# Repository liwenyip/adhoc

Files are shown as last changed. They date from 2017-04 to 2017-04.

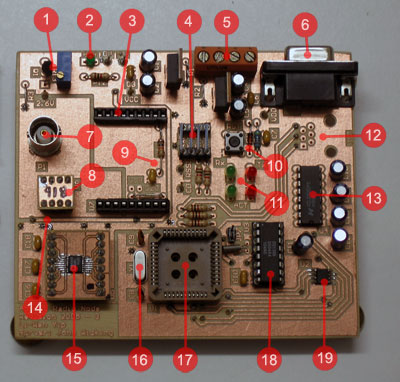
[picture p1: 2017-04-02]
docs/images/hardware/2005pcb3.jpg

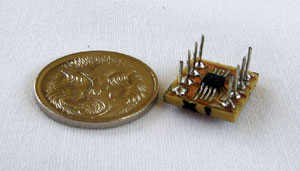
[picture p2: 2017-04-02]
docs/images/hardware/adg918-small.jpg

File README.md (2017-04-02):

# Remote Ad Hoc Sensor Networks
by Li-Wen Yip, 2005

This is my undergraduate honours thesis, completed in 2005 as part of my BE(Computer Systems).

**tl;dr**: It involved building some circuit boards with antennae, and writing a lot of code to make the circuit boards talk to each other wirelessly.

## Quick Links

- **[Website](https://liwenyip.github.io/adhoc)**: Provides a good overview of the project, and if nothing else is a great example of cutting edge web design in 2006.
- **[Presentations](Presentations)**: Also provides a good overview of the project. The first one has speaker notes in the `ppt` file; the other two don't have any speaker notes for some reason so they may make limited sense.
- **[Final report](YipThesis2005.pdf)** (PDF, 188 pages): Contains all of the juicy technical details.
- **[PCB designs](Appendix%20X%20-%20%20PCB%20Designs), [Microcontroller code](Appendix%20E%20-%20Microcontroller%20Code), [ns-2 simulator code](Appendix%20D%20-%20ns-2%20Simulation)**: Just in case you want to replicate my work.

## Licence

All of my work is published under the [MIT Licence](LICENCE.md).

## Previous and subsequent work

My thesis was a continuation of previous work by [Nigel Sim](https://eresearch.jcu.edu.au/contact/past-members/nigel-sim) (2003) and [Steven Sloots](https://au.linkedin.com/in/steven-sloots-38b22927) (2004). If you want to know more about their work, I can put you in touch with them. (I do have copies of their thesis reports, but they aren't mine to publish.)

The project was continued in 2006 by [William Harrington](http://www.harringtonsystems.com.au).

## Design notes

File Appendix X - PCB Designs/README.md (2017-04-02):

# PCB Designs

I believe these were all done using [Protel](http://www.altium.com).

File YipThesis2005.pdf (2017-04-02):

## School Of Engineering

## REMOTE AD HOC SENSOR NETWORKS

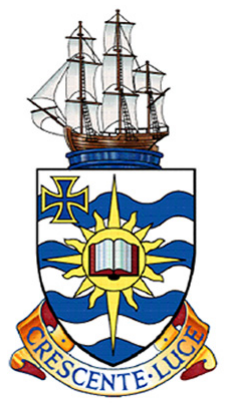
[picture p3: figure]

## Li-Wen Yip

### Bachelor of Engineering

in

### Computer Systems Engineering

# Thesis

October 2004

JAMES COOK UNIVERSITY

# SCHOOL OF ENGINEERING

EG4010

## Computer Systems Engineering

## REMOTE AD HOC SENSOR NETWORKS

Li-Wen Yip

Thesis submitted to the School of Engineering in partial fulfilment of the requirements for the degree of

## Bachelor of Engineering with Honours

## (Computer Systems)

11 November 2005

Preface | Remote Ad Hoc Sensor Networks

ABSTRACT

Australia’s vast geographical expanses present challenging communications problems for data collection, which often require the use of high power radio links. Many of these scenarios lend themselves to the use of multi-hop ad hoc sensor networks, which can provide an alternative, more flexible and economical solution. However, little if any research has been conducted into developing network protocols suitable for these scenarios, which are characterised by remote and inaccessible locations, sparse topologies, and link ranges of up to 10 kilometres.

The first goal of this project was to develop a dynamic address allocation algorithm to realise the goal of zero configuration, with minimal energy overhead. The second goal was to develop an energy efficient media access control protocol, to maximise the battery life of each node.

The MAC protocol features a synchronised wakeup, which suits the periodic bulk data transfer typical of data logging applications. During inactive periods, a preamble sampling technique provides dramatic power savings whilst maintaining minimal network connectivity. The sampling frequency is dynamically optimised for maximum power savings, based on anticipated variations in local traffic levels.

The address allocation protocol is based on an existing technique, in which each node possesses a block of addresses. These addresses may be autonomously allocated to other nodes without distributed agreement, which results in a protocol with extremely low control overhead and minimal power consumption. This technique has been optimised to further reduce the control overhead for each operation, and avoid unnecessarily flooding the network with search requests.

A microcontroller based hardware platform was constructed, and was used to develop, implement and test the aforementioned protocols. The MAC protocol has been implemented and tested on the microcontroller, whilst the addressing protocol has been implemented in the ns-2 wireless network simulator. The design of the hardware platform has also been improved, improving energy efficiency and performance.

Li-Wen Yip | School of Engineering, James Cook University | i

Preface | Remote Ad Hoc Sensor Networks

ACKNOWLEDGEMENTS

I would like to express my sincere thanks to Mr John Wicking. Without his invaluable advice and direction, this thesis project would not have been possible. I would also like to thank the ECE technical staff, whose immeasurable knowledge, experience, and common sense have saved me from many headaches.

To my friends, for sharing in the insane antics which have helped me maintain my humanity and sense of humour throughout this year, and for reminding me that there is more to life than thesis.

Finally, to my family, for supporting and encouraging me through the greater part of my life.

Li-Wen Yip | School of Engineering, James Cook University | ii

Preface | Remote Ad Hoc Sensor Networks

STATEMENT OF ACCESS

I, the undersigned, the author of this Thesis, understand that James Cook University will make the Thesis available for use within the University Library, by microfilm, or other means, and to allow access to users in other approved libraries.

All users consulting this Thesis will have to sign the following statement:

“In consulting this Thesis, I agree not to copy or closely paraphrase it in whole or in part without the written consent of the author; and to make proper public written acknowledgement for any assistance, which I have obtained from it.”

Beyond this, I do not wish to place any restriction on access to this Thesis.

Li-Wen Yip | Date
Li-Wen Yip | School of Engineering, James Cook University | iii

Preface | Remote Ad Hoc Sensor Networks

SOURCE DECLARATION

I declare that this Thesis is my own work and has not been submitted in any for another Degree or Diploma at any university or other institution of tertiary education. Information derived from the published or unpublished work of others has been acknowledged in the text and a list of references given.

Li-Wen Yip | Date
Li-Wen Yip | School of Engineering, James Cook University | iv

Preface | Remote Ad Hoc Sensor Networks

TABLE OF CONTENTS

Li-Wen Yip | School of Engineering, James Cook University | v

Preface | Remote Ad Hoc Sensor Networks
Li-Wen Yip | School of Engineering, James Cook University | vi

Preface | Remote Ad Hoc Sensor Networks
4.4.3 | Design | 87
4.4.4 | Implementation | 89
CHAPTER 5 DISCUSSION OF RESULTS | 90
5.1.1 | Hardware Architecture | 90
5.1.2 | Manchester Encoding and Decoding | 90
5.1.3 | MAC Protocol | 91
5.1.4 | Address Allocation Protocol | 92
CHAPTER 6 CONCLUSION | 93
CHAPTER 7 CONTINUATIONS AND EXTENSIONS | 95

### 7.1 Software Simulation | 95

### 7.2 Location Discovery | 96

REFERENCES | 97
APPENDIX A SOFTWARE FLOW CHARTS | 101
A.1 | Encoding and Decoding | 101
A.2 | Address Allocation | 106
APPENDIX B SCHEMATIC DIAGRAMS | 115
APPENDIX C RAW DATA | 117
APPENDIX D NS-2 SIMULATION SOFTWARE | 118
APPENDIX E MICROCONTROLLER SOFTWARE LISTING | 126
E.1 | Header Files | 126
E.2 | Modules | 134
E.3 | Peripherals | 160
Li-Wen Yip | School of Engineering, James Cook University | vii

Preface | Remote Ad Hoc Sensor Networks

LIST OF FIGURES

Figure 3.18 - Carrier Detect (Active Low), No signal present, 5V/div, 1ms/div ........59

Figure 4.3 - Carrier board soldered directly to PCB; Coaxial cable soldered directly to

Li-Wen Yip | School of Engineering, James Cook University | viii

Preface | Remote Ad Hoc Sensor Networks
Figure 4.5 - Signal strength in OFF state (-110dBm) | 72
Figure 4.6 - Clock Detect Flag vs. Frequency | 77
Figure 4.7 - Message successfully received (The answer is 42!) | 79
Figure 4.8 - Power Consumption vs. Duty Cycle for X2010 Transceiver | 81
Figure A.1 – Frame Encoder | 101
Figure A.2 - Manchester Encoder | 102
Figure A.3 - Frame Decoder | 103
Figure A.4 - Manchester Decoder | 104
Figure A.5 - High Priority Interrupt Service Routine | 105
Figure A.6 - Node Startup Event | 106
Figure A.7 - Initialisation Timeout Event | 107
Figure A.8 - AREP Message Received Event | 108
Figure A.9 - NREP Message Received Event | 109
Figure A.10 - AREQ Message Received Event | 110
Figure A.11 - Allocation Timeout Event | 111
Figure A.12 - AACK Message Received Event | 112
Figure A.13 - ASRCH Message Received Event | 113
Figure A.14 - AREJ Message Received Event | 114
Figure B.1 - Node Rev 3 Schematic Diagram | 116
Li-Wen Yip | School of Engineering, James Cook University | ix

Preface | Remote Ad Hoc Sensor Networks

LIST OF TABLES

Table 3.1 - Classification of traffic rates | 53
Table 3.2 - Hardware Parameters | 53
Table 4.1 - Instruction Cycles for Encoding Operations | 75
Table 4.2 - Frequency and Duty cycle measurements | 75
Table 4.3 - Byte Waveforms | 76
Table 4.4 - Instruction Cycles for Decoding Operations | 78
Table 4.5 - Definition of Packet | 87
Table 4.6 - Definition of Node | 87
Table C.1 - X2010 Transceiver Power Consumption vs Duty Cycle | 117
Table D.1 - DAA.H | 118
Table D.1 - DAA.CC | 120
Table E.1 - MACROLIB.INC | 127
Table E.2 - PINCONNECTIONS.INC | 127
Table E.3 - SWSTACK.INC | 130
Table E.4 - BUFFERS.INC | 131
Table E.5 - MAIN.ASM | 134
Table E.6 - PHY.INC | 137
Table E.7 - PHY.ASM | 137
Table E.8 - MAC.INC | 145
Table E.9 - MAC.INC | 145
Table E.10 - SPI.ASM | 160
Table E.11 - RTC.INC | 162
Table E.12 - RTC.ASM | 162
Table E.13 - ROUTECACHE.ASM | 167
Table E.14 - SWTIMERS.ASM | 174
Li-Wen Yip | School of Engineering, James Cook University | x

Chapter 1: Introduction | Remote Ad Hoc Sensor Networks

Chapter 1

## INTRODUCTION

### 1.1 BACKGROUND

Ad hoc networking is currently a very active area of research at many institutions around the world. A subclass of ad hoc networks are ad hoc sensor networks, which are typically characterised by long battery life, low traffic rates, low power radios, and dense, well connected topologies. The sensor nodes integrate data collection, data processing and communications functions into a tiny package with long battery life.

There are several existing projects which are at an advanced level of development, including Berkley University Smart Dust, Crossbow Motes, and the TinyOS operating system. There have also been numerous publications presenting new protocols and techniques for media access control, power management, routing, and address allocation. However, little or no research has been specifically conducted into ad hoc sensor networks which feature sparse, minimally connected topologies, and a large geographical distance between nodes. The target application is an ad hoc radio network for environmental monitoring stations on the Great Barrier Reef, which will allow data to be collected and relayed back to the Australian Institute of Marine Sciences at Cape Cleveland. This data is currently collected by high power / long range radio links, which requires expensive and bulky batteries and radios, as well as a costly radio license.

The sparse topology, remote location, and typically harsh environmental conditions present a new set of challenges, including vulnerability to the elements, varying link quality, multi-path propagation, poor SNR and interference, propagation delays, and low maintenance requirements. This scenario requires a different set of techniques and protocols to achieve the desired goals of minimal power consumption, zero configuration and planning, dynamic reconfiguration, and reliable connectivity.

Li-Wen Yip | School of Engineering, James Cook University | 1

Chapter 1: Introduction | Remote Ad Hoc Sensor Networks

### 1.2 PREVIOUS WORK

This thesis project was started in 2003 by Nigel Sim [1], who researched a very broad range of topics related to ad hoc networking. The primary focus of this work was developing a simulation environment written in Python. Several basic protocols were developed, implemented, and tested in this simulation environment, operating atop both a microprocessor based physical layer and a software simulated physical layer.

Steven Sloots [2] continued this work in 2004, focussing his efforts on developing an energy efficient routing protocol. A dynamic source routing (DSR) based protocol was developed, and modified to distribute routing information over the entire route to reduce the size of the network header and associated energy overhead. A power aware routing optimisation (PARO) was implemented, which dynamically modifies routes and transmission powers to minimise the energy cost of each route. The hardware, physical, and data link layers were also redesigned based on recommendations made by Sim.

Chapter 1: Introduction | Remote Ad Hoc Sensor Networks

### 1.3 PROPOSED WORK

The goal of this ongoing project is to develop a complete system which can be deployed on the Great Barrier Reef. With this in mind, several areas of work were identified which were required to move closer to this goal:

1. Development and implementation of a media access control protocol which conserves energy by placing the nodes’ radio transceivers in ‘sleep’ mode.
2. Development and implementation of a dynamic address allocation protocol, with primary goals of zero configuration and minimal power consumption.
3. Improvement of existing hardware and software where opportunities exist to improve efficiency, power consumption, or performance.

Chapter 2: Research | Remote Ad Hoc Sensor Networks

Chapter 2

## RESEARCH

### 2.1 POWER CONSERVATION TECHNIQUES

A primary concern in this project is to minimise the power consumption of each node, so as to obtain the longest possible battery life, reducing maintenance requirements. Steven Sloots [2] addressed this problem at the network layer by developing a power aware routing protocol, which dynamically adjusts routes and transmission powers to minimise the total energy cost of each route.

Research has shown that the energy required to monitor the medium for activity is only slightly less than that required for active communications [3]. This is supported by the specifications for the X2010 transceiver currently employed in this project: The nominal supply current is 7 mA in receive mode, 8 mA in transmit mode, and merely 1 μA in sleep mode [4]. Network traffic in ad hoc sensor networks is typically very low, thus significant power savings can be made by placing the nodes’ radios in sleep mode. This technique is typically implemented as a media access control protocol or routing extension which operates the nodes’ radios on a low duty cycle, to minimise the amount of energy wasted monitoring the channel for activity. The role of such a protocol is to determine which nodes place their radios into sleep mode, and when [5].

Power conservation in ad hoc networks is currently a very active area of research, and as such there are a plethora of existing protocols. As it would be impossible to research every existing protocol, the remainder of this section will discuss various techniques, and some of their more prominent protocol implementations.

Chapter 2: Research | Remote Ad Hoc Sensor Networks

### 2.1.1 On-Demand Wakeup

In on-demand wakeup, nodes may sleep until they are woken up by another node which wishes to communicate with it. This is typically facilitated by a secondary radio device, which can much more efficiently monitor its channel for activity due to reduced complexity requirements. Systems used for the secondary radio include RFID [6], and low power ISM band radios [7]. However, this introduces additional hardware requirements, which add to the size and cost of each node. Of greater concern is that the secondary radio must operate over the same range as the primary radio [5]. This is a particular problem in a long range ad hoc network, where distances between nodes are up to 10km. As such, this technique is not applicable to this project.

### 2.1.2 Scheduled Rendezvous

A scheduled rendezvous protocol is one in which nodes’ sleep schedules are synchronised, such that there is a communication window where all nodes are monitoring the medium. One of the problems with this technique is that adjacent nodes which have non-overlapping sleep schedules may never discover each other [5]. Another problem discussed in [5] is that this technique is not suitable for multi-hop ad hoc networks, as distributed clock synchronisation is difficult to achieve. However, this technique would be implemented at the link layer, thus clock synchronisation is only necessary between adjacent nodes.

Chapter 2: Research | Remote Ad Hoc Sensor Networks

2.1.2.1 802.11b IBSS Power Saving Mode

In 802.11b IBSS Power Saving Mode [8], synchronisation is facilitated by having nodes contend to transmit the synchronisation beacon with backoff. These beacons signal the start of a window used exclusively for handshaking, known as an ad hoc traffic indication message (ATIM) Window. Data packets are exchanged in the intervals between the ATIM windows. During the ATIM window, nodes which wish to communicate exchange ATIM messages and acknowledgements (Figure 2.1). Once the window has elapsed, nodes which sent or received ATIM messages remain awake to exchange packets, whilst all other nodes return to sleep.

Note that this protocol in its original form is not suited for multi-hop ad hoc networks, as the synchronisation mechanism will not work unless all nodes in the network can hear each other.

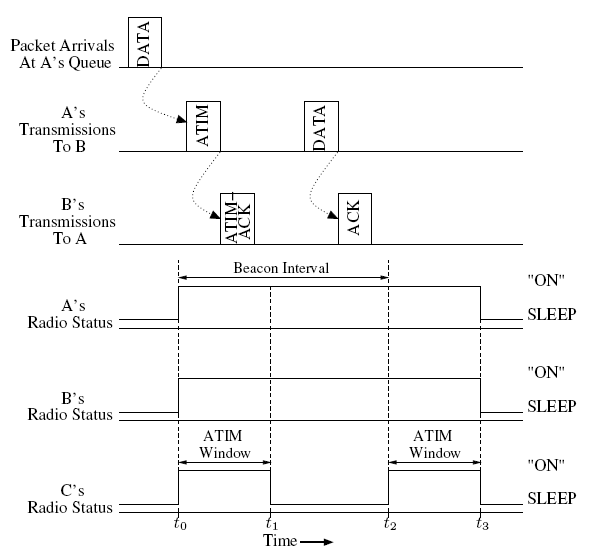
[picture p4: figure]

Figure 2.1 - IEEE 802.11 IBSS Power Save Mode [8]

Chapter 2: Research | Remote Ad Hoc Sensor Networks

### 2.1.3 Asynchronous Wakeup

An asynchronous wakeup protocol is one in which nodes’ wakeup schedules are not synchronised, instead relying on the schedules of neighbouring nodes overlapping to create a communication window for those two nodes.

2.1.3.1 Contiguous Wakeup Schedule

Feeney [9] has developed an asynchronous protocol where each sleep cycle has a single contiguous “on” period, and a duty cycle of more than 50%. Therefore, neighbouring nodes’ sleep schedules are guaranteed to overlap without requiring any synchronisation.

Each wake interval is divided into two ATIM windows and one transfer interval, as indicated in Figure 2.2. At least one of the ATIM windows is guaranteed to fall within the wake interval of each neighbouring node. During the ATIM period, nodes which wish to communicate exchange messages which allow them to estimate their phase difference, and if necessary adjust their phase to increase the amount of overlap to accommodate higher traffic. The ATIM windows are also used for broadcast and multicast traffic, although a broadcast message must be transmitted in both ATIM windows to guarantee that it will be received by all adjacent nodes.

The fundamental limitation of this approach as noted by the author is that each node must be awake for at least fifty percent (50%) of the time.

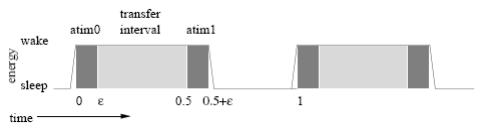
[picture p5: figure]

Figure 2.2 - Sleep/Wake Cycles [9]

Chapter 2: Research | Remote Ad Hoc Sensor Networks

2.1.3.2 Arbitrary Wakeup Schedule

Zheng et al [5] have developed a protocol in which each node’s sleep cycle is divided into a number of slots, each of which may be an “on” slot or a “off” slot. The authors demonstrate that for a cycle of a particular slot length, there exists an optimal wakeup schedule function which guarantees at least one slot overlap between any two nodes regardless of phase difference, provided that the slot boundaries are aligned. The authors go on to demonstrate that if the slot boundaries are not aligned, neighbours are guaranteed to detect each other’s beacons transmitted at the start of each “on” slot (Figure 2.3). These beacons include information that allows other nodes to calculate the sender’s schedule relative to their own, and when their schedules overlap. Outgoing packets are buffered, and transmitted when both sender and receiver are awake.

This protocol overcomes the limitation of [9] that limits the duty cycle to at least 50%. The authors give an example in which the wakeup schedule function has 73 slots, of which only 9 are “on” slots – a duty cycle of 12.3%.

However, like [9], a single message cannot be guaranteed to reach all adjacent nodes. The options for broadcasting would be to broadcast the message immediately after each beacon, or to unicast the message to all known neighbours.

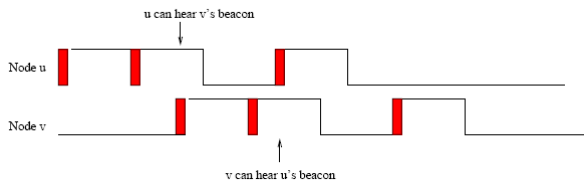
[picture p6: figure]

Figure 2.3 - Beacons in the absence of slot boundary alignment [5]

Chapter 2: Research | Remote Ad Hoc Sensor Networks

### 2.1.4 Sleep Based Routing Extensions

Several routing extensions have been developed based on the observation that there are several possible routes for a given source and destination. These protocols operate by allowing nodes which are redundant for routing purposes to conserve more power.

2.1.4.1 SPAN

In SPAN [10], “coordinator” nodes remain awake to buffer and relay packets for other nodes, forming a low-latency backbone for the network. Other nodes are thus able to operate in an asynchronous low power mode. Each node decides individually whether to become a coordinator, based on how much energy it has available, and how much energy will be saved by its neighbours. The role of coordinators is periodically rotated, such that power savings are distributed equally to all nodes.

The salient features of SPAN include improved QoS due to the formation of a backbone; however this is not important in an ad hoc sensor network. The authors also note that this technique is only useful for a minimum node density; thus it is not applicable to sparse or long range ad hoc sensor networks. This also applies to other similar protocols based on the concept of a dominating set of nodes.

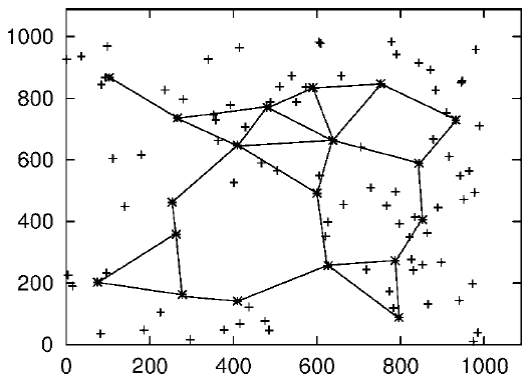
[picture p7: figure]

Figure 2.4 - A SPAN network with 100 nodes and 19 coordinators [10]

Chapter 2: Research | Remote Ad Hoc Sensor Networks

2.1.4.2 Basic Energy Conservation Algorithm (BECA)

In BECA [11], idle nodes asynchronously alternate between listening and sleeping states. If a node either transmits or receives a packet, it transitions to an active state for a predetermined timeout. Whilst a node is active it continuously monitors the medium in anticipation of further network activity. The active timeout is set to be slightly longer than the retry interval for network level requests (e.g. RREQ and AREQ messages), so that involved nodes will remain active until the operation is complete. The sleep interval is set to be an integer multiple k of the network level retry interval, which guarantees that a sleeping node will be woken after k + 1 retries.

2.1.4.3 Adaptive Fidelity Energy Conservation Algorithm (AFECA)

AFECA [11] is an extension of BECA which uses information about the local node density to dynamically modify sleep schedule duty cycles. The number of redundant routes for a particular source and destination increases with the node density, thus the duty cycle of nodes in a high density area can be decreased whilst maintaining a constant amount of routing redundancy.

As with SPAN, this technique has limited usefulness in sparse networks.

Chapter 2: Research | Remote Ad Hoc Sensor Networks

### 2.1.5 Preamble Sampling

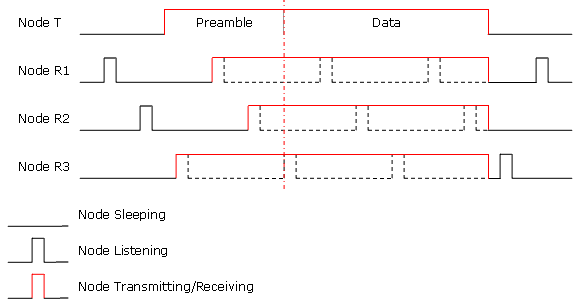
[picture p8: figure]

Figure 2.5 - Preamble Sampling

Preamble sampling (Figure 2.5) is an asynchronous technique which can be considered as an on-demand wakeup mechanism, as it uses the packet preamble to wake up sleeping nodes. Nodes periodically wake up to check for a wakeup signal (i.e. preamble). If a wakeup signal is detected, the node remains awake to receive the rest of the packet.

For a node to be woken up regardless of the phase of its wakeup schedule, the preamble must be at least the same length as one sleep cycle [12-15]. Therefore, the power savings made by the receiving node are partially offset by the energy required to transmit and receive the longer preamble.

El-Hoiydi [13] models the performance of preamble sampling when used in conjunction with Aloha [16] and CSMA [8] contention protocols, assuming fixed node densities and packet lengths. However, these results are not very useful, as they are more oriented towards optimising packet latency and throughput

Hill and Culler [15] demonstrate that by quickly measuring the energy in the channel to detect the wakeup signal, the awake interval can be reduced to 50 μs, and the wakeup signal is reduced to a long RF pulse. Conversely, if the start of frame

Chapter 2: Research | Remote Ad Hoc Sensor Networks

sequence is used as a wakeup signal, the required awake interval is up to two packet lengths, or 108 ms at 10 kbps.

WiseMAC [14], developed by El-Hoiydi and Decotignie is a preamble-sampling based protocol designed for the downlink of infrastructure wireless sensor networks. It is similar to the downlink of 802.11b BSS Power Saving Mode [8], in that the access point learns the sampling schedules of each node and hence is able to minimize the length of its packet preambles. This also has the advantage of minimizing overhearing of packets by nodes which are not the intended recipients.

B-MAC [12], developed by Polastre et al. uses adaptive preamble sampling to reduce the duty cycle for optimal power savings. However, reconfiguration is controlled by protocols and services running at higher layers. For example, this allows network layer information to be used in the decision to reconfigure, such as whether a reply is expected to the packet just sent.

Chapter 2: Research | Remote Ad Hoc Sensor Networks

### 2.1.6 Discussion

To determine the best approach to take toward designing a media access control protocol for this project, it is worthwhile to consider the typical deployment scenario for this type of network.

The nodes will typically be very sparse, with minimal connectivity, although there may be small clusters of nodes situated on reefs. The distance between adjacent nodes may be up to 10km, thus RF amplification will be used for transmission, which will make the energy cost of transmission significantly higher than that of receiving / listening. The traffic rates will be very low, with most activity occurring as a result of network layer operations (e.g. route discovery and address allocation) and data retrieval. Data retrieval will comprise every sensor node routing logged data back to a single sink node, which will occur at regular and predetermined intervals. Any MAC layer protocol also has to work in conjunction with the DSR/PARO routing protocol previously implemented by Sloots [2].

The last point is particularly important, as the PARO routing extension relies on nodes being able to overhear packets not intended for them. Therefore, both asynchronous protocols discussed [5, 9] would not be suitable, as they prevent overhearing of messages by non-involved nodes. Additionally, neither protocol supports an efficient broadcasting method. Due to the increased energy cost of transmissions, [9] is slightly better in that it only requires beacons to be transmitted when there is an impending packet transmission, however [5] requires periodic transmission of beacons.

The minimal connectivity of the network would mean that there would be very little routing redundancy, severely limiting the usefulness of both routing extensions discussed [10, 11]. Additionally, both would interfere with the PARO extension previously implemented in this project [2].

This means that the power save protocol should be based on either scheduled rendezvous, or preamble sampling. In fact, a combination of the two techniques may be useful, as follows in the conclusion.

Chapter 2: Research | Remote Ad Hoc Sensor Networks

### 2.1.7 Conclusions

Recall that the majority of network traffic will be caused by either network level operations or transfer of data from sensors nodes to the sink node. Since a reactive routing protocol is used, route requests will only occur when there are impending data packets. Therefore, the only network traffic which will not occur on a predictable schedule is as a result of addressing operations, which mostly occur when the network is initially deployed.

Consider an example, where data is collected from sensor nodes once every six hours, and that data collection can be completed in one minute. Therefore, if a network-wide rendezvous is scheduled for one minute every six hours, the duty cycle of the system is reduced to approximately 0.28%, with no detrimental effects on packet latency or throughput.

Synchronizing the clocks of adjacent nodes to within one second is a non-trivial problem, and the propagation of synchronisation messages can be initiated by the sink node. However, having such a long sleep interval makes it impossible for asynchronous network operations to occur during this period, including address allocation and the initial synchronisation of nodes.

A possible solution is instead of defining global “awake” and “sleep” periods, define periods as “high traffic” and “low traffic” respectively. A preamble sampling technique can be used during the low traffic periods. Communication during these periods will be more energy expensive due to the increased preamble length; however the network is able to retain minimal connectivity. By using adaptive techniques to anticipate network activity similar to those used in [11, 12], the preamble energy overhead during the power save interval could be significantly reduced for network operations such as address requests.

For example, when an initialising node sends an address request, the network layer may instruct the MAC layer to wait the duration of the retry interval before reverting to power save mode, and instruct the MAC layer in neighbouring nodes not to use the extended preamble.

Chapter 2: Research | Remote Ad Hoc Sensor Networks

Moreover, the energy sampling technique used in [15] is equally applicable to the X2010 transceiver currently employed in this project. The X2010 data sheet [4] shows that the time from power up required to obtain a valid data is 5 ms, whereas the time required to obtain a valid RSSI reading is only 1ms. These concepts will be further developed in section 3.4 (p. 50).

Chapter 2: Research | Remote Ad Hoc Sensor Networks

### 2.2 DYNAMIC ADDRESS ASSIGNMENT PROTOCOLS

### 2.2.1 Introduction

Automatic configuration is a desirable feature for any system, as it eliminates the need for a skilled technician to assist with the deployment. One of the important functions of automatic configuration is dynamic address assignment, also known as dynamic address allocation, or simply dynamic addressing. Dynamic addressing refers to the process by which nodes automatically obtain a routable address upon joining a network. This is as opposed to static addressing, whereby a node is manually configured with an address before it joins a network. Dynamic addressing has many advantages over static addressing:

1. Automatic configuration – allows easy deployment.
2. Allows nodes to move freely between networks.
3. Allows addresses to be recycled if the corresponding nodes have left the network.
4. It can cope with the dynamic nature of ad hoc networks.

In traditional TCP/IP networking, dynamic addressing is achieved exclusively with the ubiquitous Dynamic Host Configuration Protocol (DHCP), however the lack of static infrastructure in an ad-hoc network precludes its use. The following sections shall go on to investigate existing research into developing dynamic addressing protocols for ad hoc networks.

Chapter 2: Research | Remote Ad Hoc Sensor Networks

2.2.1.1 Ad Hoc Network Dynamics

Ad hoc networks are of a very dynamic nature, with constantly changing network conditions, which the dynamic addressing protocol must have mechanisms to deal with. The changes that may occur can be classified into five distinct network events:

1. Network creation – an unconfigured node creates a new network, in the event that it cannot find any existing networks within communication range.
2. Node join – An unconfigured node joins the network. The protocol must ensure that a unique address is allocated to the node.
3. Node part – A node leaves the network. The protocol must ensure the release of the node’s address to make it available for reallocation.
4. Network partition – The network is split into two parts either by a broken link or crashed node. The protocol must ensure that each partition is still able to continue operating as an independent network.
5. Network merge – Nodes from two independent networks come within communication distance of each other. The protocol must detect and eliminate duplicate addresses to allow the two networks to be merged.

Chapter 2: Research | Remote Ad Hoc Sensor Networks

2.2.1.2 Objectives

Sun and Belding Royer [17] list the following objectives for an ad hoc network dynamic address assignment protocol:

1. Dynamic Address Configuration – Addresses are allocated without manual or static configuration.
2. Unique Address Allocation – Each node is allocated a network-unique address.
3. Robustness – The protocol should have mechanisms to deal with network merges and partitions.
4. Scalability – The protocol should be applicable to networks of varying sizes without an adverse impact on its performance. The relevant performance metrics include timely address allocation, and minimal control overhead during address allocation.

The intended application of this thesis project is the monitoring of remote and inaccessible outdoor locations. Such a network would comprise sparsely distributed nodes, with inter-node hops of up to several kilometres. A likely scenario is that the nodes will be deployed in fixed locations, and network maintenance will consist of replacing nodes whose batteries have expired.

Therefore, the primary goal is to minimise the need for network maintenance by minimising the power consumption of the network. The largest consumer of energy in an ad hoc network is radio communications [18], especially in sparse networks where energy consumption is a function of the distance squared. Pottie and Kaiser [19] illustrate this concept with an example, where transmitting 1 kilobyte of data a distance of 100m uses the same amount of energy as performing 3 million instructions in a 100MIPS/W processor.

There are two ways in which the addressing algorithm can reduce the power consumption of the network:

Chapter 2: Research | Remote Ad Hoc Sensor Networks
1. Minimise the control overhead of network operations. This may be achieved by reducing the number of packets that must be transmitted to complete a network operation.
2. Minimise the network addressing overhead. Network addresses are transmitted in the network header of every packet transmitted, introducing network overhead, and associated energy consumption. This overhead may be significantly reduced by limiting the address space [20].

2.2.1.3 Classification of Address assignment protocols

The address assignment protocols developed to date may be divided into three classifications according to their fundamental concept of operation:

1. Decentralised protocols, in which no one node has definitive knowledge of all the addresses in use.
2. Leader based protocols, in which a single node keeps a definitive record of every address in use.
3. Hybrid protocols, where every node possesses a subset of the total address space, which it can allocate parts of to other nodes.

2.2.1.4 Terminology

Here are definitions of the terms to describe node operations and states in this work.

1. Requesting Node: The node which wishes to join a network
2. Attachment Agent / Initiator node: The node which is responsible for requesting an address on behalf of the Requesting Node.
3. Address request (AREQ): the message broadcast to the network to enquire if the candidate address is unique
4. Address reply (AREP): the message unicast back to the requesting node informing whether the address is unique

Chapter 2: Research | Remote Ad Hoc Sensor Networks

### 2.2.2 Decentralised Protocols

In decentralised protocols, no one node has a definitive list of every address in use throughout the network, so there must be a decentralised method of allocating unique addresses.

Most decentralised protocols rely on some form of Duplicate Address Detection (DAD). In the simplest form of DAD, the requesting node randomly selects a tentative network address, and broadcasts an address request (AREQ) message to determine if the address is already in use. Nodes which receive the AREQ may issue an address reply (AREP) message to indicate that the address is already in use. Such an approach is employed in IPv4 Link-Local Dynamic Address Allocation (ZeroConf ) [21]. However, there are a number of problems with applying this approach to ad hoc networks, which shall be discussed in the following sections.

2.2.2.1 Routing To Uninitialised Nodes

The ZeroConf protocol is only applicable to link-local networks, i.e. all the nodes in the network are totally connected by physical or logical links, thus AREP messages can be reliably delivered to the requesting node. However, in a multi-hop ad-hoc network, if the tentative address is not unique, AREP messages may not be correctly routed.

Perkins et al. [22] propose a scheme which attempts to reduce the probability of this event. In addition to selecting a candidate address, requesting nodes select a temporary source address from an address range reserved for this process, thus guaranteeing that the source address will not be in use by any existing nodes. However, there still exists the small possibility that two requesting nodes may simultaneously select the same temporary source address, in which case AREP messages may not be correctly routed [23, 24].

The protocols proposed in [20, 24] solve this problem by using an attachment agent to perform the duplicate address detection on behalf of the requesting node. The attachment agent is already has a unique address, thus the network can reliably route AREP messages to it. The attachment agent and the requesting node can reliably exchange messages, as they have share a direct link.

Chapter 2: Research | Remote Ad Hoc Sensor Networks

2.2.2.2 Limited Address Space

It can be observed that for simple DAD to perform efficiently, the ratio between the size of the available address space and the size of the network must be quite large. In [21, 22] the 169.254/16 address range (approx. 65,000 addresses) is reserved for this purpose, giving a host joining a network comprising 1300 hosts a 98% chance of selecting an unused address on its first attempt [21]. However, bandwidth is a very limited resource in ad hoc sensor networks [25], thus it is desirable to conserve bandwidth by reducing the address length and thus the addressing overhead.

In MANETconf [24], each node maintains a record of the addresses it knows to be in use, allowing the attachment agent to select an address which has a high probability of being unused. All nodes which receive the AREQ from the attachment agent, must acknowledge it; this enables the attachment agent to release addresses which it does not receive replies from, providing a mechanism to detect crashed nodes. Together, these features make MANETconf applicable to networks with a limited address space. In fact, it restricts usage to networks with a limited address space, as every node must have sufficient memory to store the address of every node in the network.

Boleng [20] proposes a variable length addressing scheme in which the address space grows with the size of the network. All nodes maintain two addressing parameters: ADDR_LEN, the current address length in use, and HIGH_ADDR, the highest address in use. This allows addresses to be allocated sequentially instead of randomly. However, the maintenance of these parameters adds overhead to the network, especially when the address space is incremented. Furthermore, the protocol does not provide a mechanism to recover addresses from crashed nodes.

2.2.2.3 Unbounded Delays

Nesargi and Prakash [24] discuss the importance of selecting timeout periods for DAD attempts. The timeout period is a compromise between timely address allocation, and the chance of failing to detect duplicate addresses too far away from the requesting node. The authors state that to ensure that all duplicate addresses are detected, the timeout period must be a function of the diameter of the network, which in the worst case can be O(n), where n is the number of nodes.

Chapter 2: Research | Remote Ad Hoc Sensor Networks

Furthermore, Vaidya [26] presents the following theorem:

“Strong DAD cannot be guaranteed if message delays between at least one pair of nodes in the network are unbounded.”

In a sparse outdoor ad hoc network, partitions due to weather conditions or node failures may result unbounded message delays, thus causing DAD to fail. Considering that such partitions are usually temporary, the resulting message delays could be considered bounded, but the timeouts required to ensure success are impractically long.

MANETconf addresses this issue by maintaining state information, i.e. each node has a list of all the addresses it knows to be in use. If the initiator node receives affirmative AREP messages from all the addresses in its list, it can be fairly certain that the candidate address is not in use without waiting for the timeout to expire.

2.2.2.4 Control Overhead

As previously mentioned, bandwidth is a very limited resource in ad hoc sensor networks [25]. Every DAD based protocol discussed so far have one common disadvantage – each address allocation operation requires the network to be flooded with an AREQ message, thus a non-trivial amount of bandwidth is consumed each time a node joins. In particular, MANETconf [24] requires all nodes to unicast AREP messages in reply to a AREQ message. The amount of bandwidth consumed is related to the size of the network, thus the scalability of these approaches is generally poor. This is an intrinsic disadvantage of distributed DAD based approaches, and there is little that can be done to mitigate it without introducing some sort of centralisation. Sun and Belding-Royer propose such a scheme which combines DAD and centralisation [27], which shall be discussed in the following section.

Chapter 2: Research | Remote Ad Hoc Sensor Networks

### 2.2.3 Leader-based Protocols

Leader-based protocols employ a single node to maintain a definitive list of addresses in use throughout the network. This node may perform two functions:

1. Verify the uniqueness of a node’s tentative address.
2. Directly allocate unique addresses to nodes.

The classic example of a leader-based protocol is the dynamic host configuration protocol (DHCP) [28], a client-server based protocol for automatic configuration of clients in TCP/IP networks. The protocol includes a dynamic address allocation mechanism, in which the DHCP server allocates addresses to clients on a renewable time-limited lease. If the client allows the lease to expire, the address will be made available for allocation to other clients, allowing addresses to be reused without being explicitly released by the client.

However, ad hoc networks are by definition devoid of static infrastructure, precluding the use of DHCP in its traditional form. The leader-based protocols researched [27, 29] all elect a leader from amongst the nodes which form the network. These protocols are discussed further in the following sections.

2.2.3.1 Dynamic Address Configuration Protocol (DACP)

Sun and Belding-Royer [27] propose a protocol based on [22] which combines DAD and a centralised Address Authority (AA). (This protocol is referred to by the same authors in [17] as DACP). The first and second nodes to join the network respectively assume the roles of Primary Address Authority (PAA), and the redundant Backup Address Authority (BAA).

The PAA periodically broadcasts a beacon message, advertising its presence to the network. A node may detect a network partition if it stops receiving beacon messages from the PAA, in which case a new PAA is elected for the partitioned network. If the BAA is inside the partitioned network, it may automatically take over as the PAA. Conversely, a node may detect a network merge if it receives beacon messages from two different PAAs, in which case the two PAAs will exchange address lists and eliminate and reallocate duplicate addresses.

Chapter 2: Research | Remote Ad Hoc Sensor Networks

A requesting node selects a candidate address and a temporary sources address, and performs DAD in an identical manner to that described in [22]. If a duplicate address exists, either the node possessing the duplicated address or the PAA may reply with an AREP message, which allows for faster detection of duplicate addresses. However, there is no mechanism to speed up confirmation that the candidate address is unique.

Once the requesting node is satisfied that its candidate address is unique, it registers its address and requested lease duration with the PAA. The lease mechanism is identical to that used in DHCP [28], allowing an address to be released if the node does not renew its lease, whilst allowing temporarily disconnected nodes to retain their addresses.

The authors also argue that because routing information is accumulated by the AREQ messages, the AREP message can be routed back to the correct recipient even if two requesting nodes are concurrently using the same temporary source address. However, they do not consider the case where the two requesting nodes share an identical route, which has a reasonable probability in very small networks.

2.2.3.2 Optimised DACP (ODACP)

Sun and Belding-Royer propose in [17] an optimised version of their DACP protocol sans DAD and the associated overhead, resulting in a pure leader-based scheme. Instead of flooding the network with AREQ messages, the requesting node unicasts the AREQ message to the PAA.

2.2.3.3 Dynamic Address Allocation Protocol (DAAP)

Patchipulusu [30] proposes a scheme in which the last node to join the network takes on the responsibility of being the leader. Addresses are assigned sequentially, and all nodes keep a record of the highest address in use (the address of the leader). All nodes periodically broadcast “hello” messages containing a network identifier, which facilitates the detection of network merges and partitions.

Chapter 2: Research | Remote Ad Hoc Sensor Networks

### 2.2.4 Hybrid Protocols

In a hybrid protocol, every node is a leader with the authority to allocate addresses from a subset of the address space.

2.2.4.1 Nigel Sim’s Solution

Nigel Sim [1] proposes a scheme based on a binary tree, where each node has the authority to assign two child addresses, which consist of a single bit appended to the parent’s address. This concept has the advantage of variable address length. However, this scheme does not consider the case where a requesting node is unable to establish a direct link to a parent which has not already assigned both its child addresses, nor does it consider the topology of the network. Consider the best case scenario, where the topology of the network is a complete binary tree. The required address length would be log2 n, i.e. there would be few wasted addresses. However, consider the worst case scenario, where the network has a linear topology, which would require n bit long addresses, i.e. there would be 2n
– n wasted addresses. This scheme is clearly only suitable for dense networks where the topology remains static for the lifetime of the network. However, [23, 31] (which are discussed below) make use of this concept of each node having authority over a subset of the address space resulting in low maintenance addressing schemes with little overhead.

2.2.4.2 Address Pool Protocols

Both Tayal and Patnaik [23] and Hu and Li [31] have presented protocols based on the address pool concept. Instead of a single address, each node is allocated a set of addresses, the first address of which it uses for itself. Upon request, it will relinquish part of its address pool to a requesting node. This operation does not require multi-hop routing or distributed agreement, thus mitigating the disadvantages common to other protocols such as flooding messages, non-trivial timeouts and delays, protocol modifications, overhead of periodical maintenance messages, and major address leaks [31]. Another major advantage is that partitioning and subsequent remerging of a network need not incur any control overhead. The two hybrid protocols reviewed here differ primarily in their solution to the address depletion problem, where a joining node is not in range of an existing node which possesses an available address.

Chapter 2: Research | Remote Ad Hoc Sensor Networks

2.2.4.3 ZAL: Zero-Maintenance Address Allocation

ZAL [31] takes a proactive approach to the address depletion problem, using the ZAL Distribution Equalization (ZAL/DE) algorithm. ZAL/DE promotes even distribution of addresses throughout the network by attempting to ensure there are a predetermined number of available addresses within transmission range of any node in the network. Nodes which possess surplus addresses will attempt to distribute them to other nodes. However, this process will only occur when absolutely necessary to maintain the minimum number of available addresses in an area, thus there is no control overhead in a stable network.

In the event that a requesting node cannot obtain an address from any of its immediate neighbours, it randomly selects a temporary address from a reserved address range until it can obtain a permanent unique address. However, this assumes the node is mobile, and will eventually come into direct contact with a node which has an available address. This obviously will not work for a sensor network in which all the nodes are static. Furthermore, this solution does not provide a mechanism to reclaim leaked addresses.

2.2.4.4 The Tayal and Patnaik solution

The solution proposed by Tayal and Patnaik [23] takes a reactive approach to the address depletion problem. When a requesting node cannot contact a node that has available addresses, the attachment agent floods the network with a request for an available address pool. This process also provides a mechanism to reclaim leaked addresses; any nodes which no not respond to the address request within a bounded timeframe can have their address pools reclaimed. Any reclaimed address pools are always repossessed by a node which contains an adjacent address block. This eases the memory requirements on the nodes, as the address pools will always be a contiguous block, which can be defined by its start and end addresses.

Chapter 2: Research | Remote Ad Hoc Sensor Networks

### 2.2.5 Discussion

To determine the best approach to the address allocation problem for this project, it is worthwhile to consider the most likely deployment situation for this type of network.

The network will most likely be deployed outdoors, with a distance between the nodes of up to 10km. Most of the nodes will be deployed when the network is initially set up, and additional nodes may be added or removed throughout the life of the network. Nodes may crash as their batteries fail, or due to equipment failure. Weather conditions may temporarily affect the link quality, potentially causing temporary network partitions and subsequent remerges. Other devices operating in the same ISM band may cause interference, which may interfere with the operation of one or more nodes, potentially causing temporary network partitions.

A key point here is that most network partitions will be temporary. Whilst the network partitions must be able to continue operating until they are remerged, it is a potential waste of energy to establish new network infrastructure for each partition if they are inevitably, going to be remerged. The hybrid protocol concept is very suitable in this respect, as there is no control overhead for a network partition and subsequent remerging.

The salient feature of the Tayal and Patnaik solution [23] is its simplicity, and that all operations remain local unless address depletion occurs. The principle of contiguous address spaces is very desirable, as it eases memory requirements, and reduces the bandwidth required for nodes to exchange address spaces.

The other impressive feature of ZAL [31] is that it proactively ensures even distribution of addresses throughout the network. The authors claim that the network requires zero maintenance once it has reached a stable state, however reaching a stable state comes with a non-trivial energy cost, particularly in a sparse network.

However, ZAL does have some passive features which promote even distribution of addresses. For example, a requesting node does not accept the first address offer it receives. Instead, it waits for all replies to arrive, then accepts the largest offer. This increases the time it takes to obtain an address, but it does not make the operation any more energy expensive.

Chapter 2: Research | Remote Ad Hoc Sensor Networks

A potential area in which the Tayal and Patnaik protocol can be improved is the method used to search the network for available addresses. The authors specify that if a node receives an address request but does not possess any available addresses, it immediately floods the network with an address search message. Therefore, even if other nodes which received the address request are able to provide addresses to the requesting node, this message will be flooded to the network. This method could be improved to only propagate the search message when it is absolutely necessary, thereby conserving energy.

### 2.2.6 Conclusions

It is clear that the address allocation protocol for this project should be based on the hybrid protocols [23, 31], primarily because of their ability to deal with temporary network partitions, and low control overhead. The protocol to be developed will attempt to incorporate the salient features of both protocols, as well as adaptations to conserve energy in a sparse long range network. The operation of this protocol is discussed further in section 3.5 (p. 60).

Chapter 3: Development | Remote Ad Hoc Sensor Networks

Chapter 3

## DEVELOPMENT

### 3.1 HARDWARE ARCHITECTURE

The hardware platform previously designed by Sloots [2] worked successfully, and as such will only be subject to minor improvements, the main goal of which will be decreasing power consumption. A block diagram of the 2004 hardware platform is shown below in Figure 3.1.

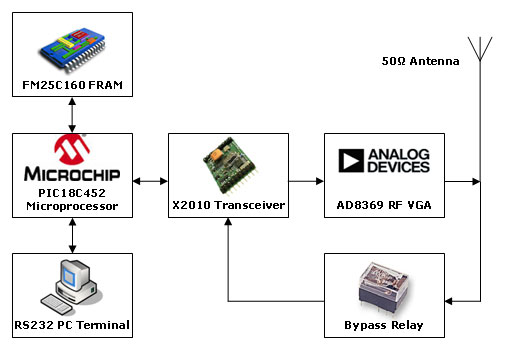
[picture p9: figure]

Figure 3.1 - 2004 Hardware Block Diagram

### 3.1.1 VGA Bypass Problem

As can be seen in Figure 3.1, an X2010 transceiver module is used in conjunction with an AD8369 Variable gain amplifier (VGA) to provide programmable output power, as required to implement the power aware routing extension developed in 2004. The transceiver only has one antenna connection; hence a relay provides a return signal path around the VGA to allow reception. This was an improvised solution, and as a result is far from ideal:

1. The relay contact closing time causes an additional delay when switching between receive and transmit modes. This delay was found to be between 5 and 15 milliseconds [2], which exceeds the X2010 transceiver’s inherent switching delay of 5 milliseconds.
2. The current required to reliably latch the relay contacts is typically 550mA, which the microprocessor must drive via a switching transistor [2]. More importantly, this incurs a power consumption of 2.75W¹
, which
is clearly unacceptable in an application where power conservation is an important criterion.

Several solutions to this problem were considered. One option was to retain the same configuration, but use a low power relay. The lowest power relay available through Farnell InOne is the NEC EF2 ultra low power relay [32], which has a power consumption of 50mW, and an operation time of 4ms. However the device is expensive, costing $14.51 (AUD) for a single unit.

A second option was to eliminate the bypass relay by using separate transmitter and receiver modules, which allows for two separate antennae. However, this would increase the size and cost of each node.

1
Power consumption is based on a power supply of 5 Volts DC.

A third option was to use a transceiver module with programmable output power. The LPRS ER400TRS “Easy Radio” transceiver module [33] features programmable output power, frequency, and data rate, and handles low level functions such as Manchester encoding and buffering. This would eliminate the bypass relay, the AD8369 VGA, and the software Manchester encoder/decoder. Unfortunately, the maximum output power for the device is only 10mW. To maximise communications range, the nodes should be able to transmit at the maximum allowable power for licence free transmission, which for the Australian 433 MHz band is 25 mW. If this device were available with a higher transmission power, it would be the ideal solution.

The chosen solution was to replace the relay with a solid state CMOS switch, which is far smaller and consumes an insignificant amount of power. General purpose CMOS switches are unsuitable for switching high frequency signals due to impedance problems. However, Analog Devices produces a range of wideband analogue switches specially designed for RF applications (ADG918/919, [34]). These devices provide low insertion loss in the ‘ON’ state and high port separation in the ‘OFF’ state at frequencies up to 1 GHz, and have very low power consumption (~1uA). Unfortunately, the devices only operate over 1.65V – 2.75V, and will hence require a separate power supply.

A suitable power supply for a low current device is an emitter-follower voltage source. Sources of this type would typically use a Zener diode to provide a reference voltage (Figure 3.2a). However, to operate a Zener diode in its Zener region requires approximately 10mA of current, which is not acceptable overhead for this application. The alternative is to use a resistor voltage divider to provide the reference voltage (Figure 3.2b). Achieving a precise ratio with discrete resistors is difficult at best, thus a trimmer potentiometer will be used in the prototype allowing the voltage to be tuned to the correct level.

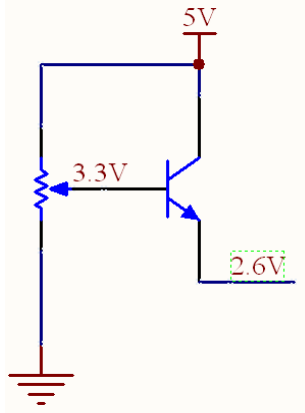
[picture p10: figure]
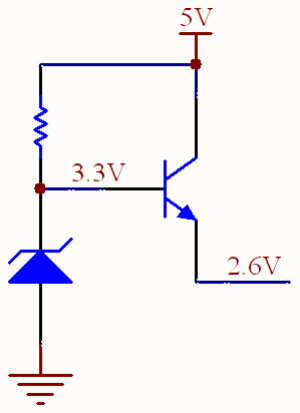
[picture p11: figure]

a) Zener diode as reference | b) Resistor voltage divider as reference
Figure 3.2 - Emitter Follower Voltage Sources

### 3.1.2 New Hardware Requirements

3.1.2.1 Real Time Clock

A real time clock is to be included in this hardware design for several reasons:

1. To enable accurate scheduling of data sampling.
2. To allow data samples to be time stamped.
3. To allow accurate timing of sleep-wakeup schedules.

The RTC device should feature programmable alarms that are capable of generating hardware interrupts for the PIC microcontroller. A suitable device was found in the Maxim-Dallas DS1305 Serial Real Time Clock [35], which features two programmable alarms with separate interrupt lines, and a SPI interface.

### 3.2 SOFTWARE ARCHITECTURE

### 3.2.1 The OSI Model

The Open Systems Interconnect Model (OSI Model) divides the functions of a communication system into 7 layers of abstraction. This model allows a communication system to be designed as a ‘stack’ of protocols, each of which implement the functionality of a layer.

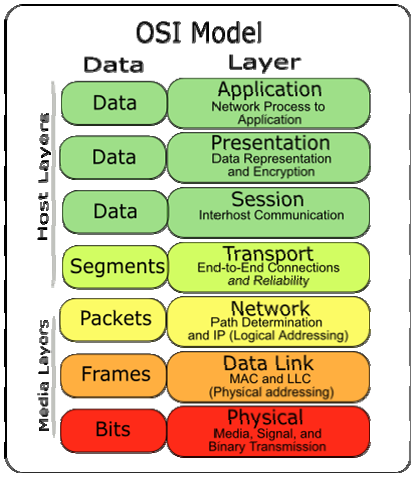
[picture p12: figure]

Figure 3.3 - The 7 Layers of the OSI Model [36]

The key concept of the OSI Model is encapsulation, which defines the way in which the layers interact with each other. Each layer is only dependent on the functionality of the layer immediately below it, and only provides functionality to the layer immediately above it.

The protocol layers in different devices communicate with each other using a Protocol Data Unit (PDU), which comprises a header containing information specific to that protocol layer, and a data section which encapsulates the PDU of the next higher layer. The header is removed before the PDU is passed up to the next higher layer, so a particular layer will only ever see its own PDU. This allows a communications system to encompass many devices using different communications protocols and transmission media.

This thesis project is only concerned with developing a network access module, which comprises the first three layers of the OSI Model. The descriptions of these layers according to Wikipedia [36] are given below.

3.2.1.1 Physical Layer

The physical layer defines and implements the mechanical and electrical interface ary function is to convert the data as it is represented within the device into a signal suitable for the communication medium, i.e. an electrical,

1. Transceiver hardware.

tter, and decoding and synchronisation at the

3.2.1.2 Data Link Layer

between devices. Its prim

light, or radio signal, and to convert it back at the receiver.

Important aspects of the physical layer for a radio based system include:

2. Transmission frequency.
3. Baud rate.
4. Encoding at the transmi
receiver.
5. Establishment and termination of transmissions.
The da | mes between two devices nt link. The data link layer is further divided into two sub-

layers: the Media Access Control (MAC) layer, and the Logical Link Control (LLC)

AC layer converts the raw bit stream received by the physical layer into frames, includes:

3. , and verification of the CRC.

ta link layer ensures the reliable transmission of fra which share a point-to-poi

layer.

3.2.1.2.1 Media Access Control Layer

The M
which are the data link layer PDU. This
1. Delimiting the frames at the transmitter, and extracting frames from the bit stream at the receiver.
2. MAC Addresses, filtering frames not intended for the device.

Calculation, appending

4. Controlling access to the media i.e. Carrier Sense Multiple Access

3.2.1.2

The LLC layer is responsible for converting between network layer packets and data

sembling them at the receiver. (Type 1, 2, 3)

3.

The LL

3.2.1.3 Network Layer

(CSMA).

.2 Logical Link Control Layer

link layer frames. This includes:

1. Fragmenting network layer packets which are too large into smaller MAC layer frames, and reas
2. Ensuring reliable point-to-point delivery of frames. (Type 2, 3)

Reassembling frames in the correct order. (Type 2)

C layer is not implemented in this project.

message between any two nodes in s:

allocation.

to MAC layer addresses.

The network layer is responsible for conveying a the network. This include

1. Global network layer addressing.
2. Dynamic address
3. Resolving network layer addresses
4. Routing.

### 3.2.2 Relocatable Code

Assembly language programs for Microchip PIC microprocessors are traditionally compiled as absolute code, meaning that the executable code is generated directly from a single monolithic source file, and program and data memory addresses are assigned at compile time.

The software developed by Steven Sloots was written in this manner, with the source file containing over three 3000 lines of code, 120 cryptic variables, and 350 code labels and constants. This made the code very difficult to understand and work with, and was exacerbated by a lack of comprehensive commenting and documentation.

The introduction of MPASM v2.00 and MPLINK v1.00 [37] allows the generation of relocatable code, meaning that several source files are compiled into individual object modules. These object modules are then combined by a linker to generate executable code (Figure 3.4). This has several advantages over absolute code generation:

1. The program can be split into several independent and reusable code modules.
2. Each module has a separate namespace for program and data memory labels.
3. Only the affected modules need to be recompiled when changes to the program are made.

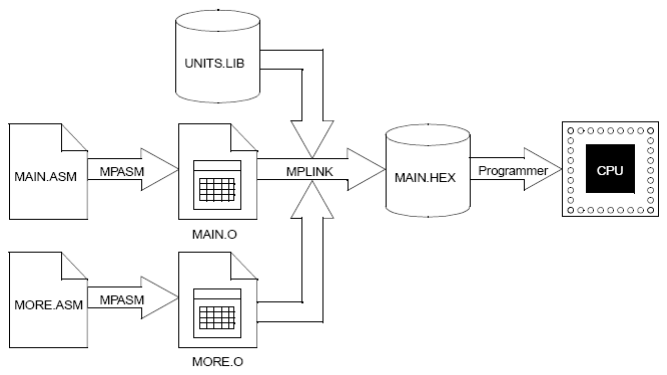
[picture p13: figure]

Figure 3.4 - Generating Executable Code from Object Modules [37]

The software will be redeveloped for this project using relocatable code, with these specific objectives:

1. Make the code modular, reusable, and easy to understand.
2. Limit the scope of each code module to a single protocol, so that each protocol can be worked on independently.
3. Create a well defined interface for each code module, to promote encapsulation and reusability.
4. Consistent standard of comprehensive commenting, especially for each subroutine / code block (not just line-by-line comments).
5. Create comprehensive documentation in the form of module interaction diagrams and flow charts.
6. Allow the code to be easily extended in future projects.

### 3.3 MANCHESTER ENCODING AND DECODING

As stated earlier, the X2010 radio transceiver is AC coupled on its data pins, thus the data must be Manchester encoded to ensure that there is no DC component in the transmitted bit stream. This introduces the need for the following functions:

1. Manchester encoding.
2. Manchester decoding.
3. Clock synchronisation at the receiver.

### 3.3.1 Introduction

Most digital coding schemes involve multiplying (XOR) the data sequence with a code sequence. In many schemes, the length of the code sequence is equal to the length of one data bit, so that a high data bit is encoded a single iteration of the code sequence, and a low data bit is encoded as an inverted iteration of the code sequence. The encoded bits are referred to as chips. The effective data rate, or chip rate is given by:

Chip rate = Data rate * Code sequence length | (3.1)

Manchester encoding uses the code ‘10’ thus a data bit 1 is encoded to 10, and a data bit 0 is encoded to 01. The code is two bits long, so the chip rate will be twice the data rate.

An equally valid alternative definition is based on transitions, with a data bit 1 being encoded to a rising edge, and a data bit 0 being encoded to a falling edge.

### 3.3.2 Manchester Encoding

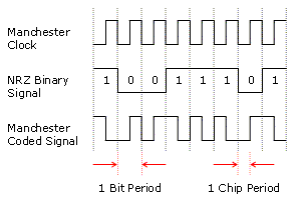
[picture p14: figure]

Figure 3.5 – Manchester Encoding

The hardware implementation of Manchester encoding is to multiply the raw data stream with a 50% duty cycle clock running at the data rate (Figure 3.5), which Sloots
[2] successfully converted to a software implementation. This software is executed under a compare interrupt running at the chip rate, allowing the output to be manipulated once at the beginning of every chip period.

However, there is a minor flaw in this software - interrupt latency and the time taken to calculate the new output value may vary, causing the encoded clock signal to drift in phase (Figure 3.6).

No problems are anticipated unless the clock rate is increased relative to the processor speed, however there is a simple solution: The value of each chip can be calculated one chip period in advance, therefore as long as the calculations take less than one chip period, the clock will remain in perfect synchronization. This is easily implemented by programming a compare output pin to change at the instant the interrupt occurs.

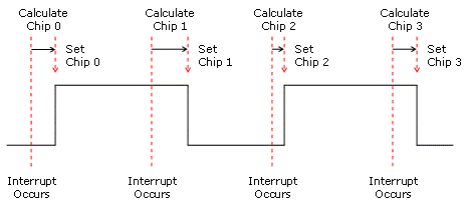
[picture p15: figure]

Figure 3.6 - Manchester Clock Drift

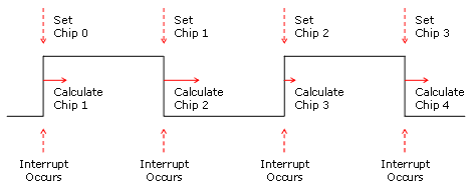
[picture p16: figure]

Figure 3.7 - No Clock Drift

### 3.3.3 Manchester Decoding and Synchronisation

Sloots [2] previously developed a software decoding algorithm based on asynchronous serial transmission. Both the start and stop bits are high (1→0), so that there is always a rising edge at the start of the byte. The decoder detects this edge via external interrupt, waits 1/2 a chip time, then takes 20 samples, 1 chip time apart. Framing errors are detected by verifying both the start and stop bits, and verifying that the second chip of each bit is inverted. However, there are some major flaws with this algorithm, as described below.

Firstly, the receive data pin of the X2010 transceiver does not have an mark state when a signal is not present, rather it outputs a stream of randomly spaced pulses. (Figure 3.8). The aforementioned decoding algorithm will detect one of these as a start bit after a carrier is detected, but before the incoming signal stabilises, which will likely cause a framing error. This means that there must be a mark state for at least one byte period after the incoming signal has stabilised, to allow the receiver to correctly detect the first start bit. However, there is no way to achieve this; when a DC signal is fed into the transmitter, the receiver still outputs a stream of randomly spaced pulses, albeit less frequently.

Secondly, because the samples are not processed until all 20 have been taken, the decoder has no way of detecting a framing error until one byte period has elapsed. This poses a problem with a Manchester encoded signal: during the synchronisation header, the clock embedded in the signal may trigger another sampling routine as soon as the previous one has finished, meaning the decoder may never synchronise to the start of the frame (Figure 3.9).

Thirdly, the start and stop bits on each byte are currently serving to synchronise the receiver to the start of each frame, which is essentially using an asynchronous synchronisation technique to decode a synchronous transmission. Much more precise synchronisation can be achieved by extracting the clock from the data signal, hence these bits unnecessarily incur a 25% bandwidth overhead.

Figure 3.8 – RxD with no signal present; 5V/div; 1ms/div

Figure 3.9 - Repeated framing errors

It is clear that the decoding algorithm must be improved so that synchronisation can be achieved more quickly, reliably, and with less overhead. The problem of decoding and synchronisation exists at two levels:

1. Clock synchronisation, i.e. synchronising to the start of each data bit. This is the responsibility of the physical layer.
2. Synchronising to the start of each frame (packet). This is the responsibility of the data link layer.

3.3.3.1 Clock Synchronisation

Sim [1] discussed three methods of clock synchronisation for a Manchester encoded data stream:

1. Over-sampling.
2. Edge Timing.
3. Synchronous logic, combining edge timing and sampling.

Sim [1] developed an over-sampling method, which takes 4 samples within each chip period. Clock synchronisation is ensured by waiting for the edge in the middle of each bit. However, the algorithm requires a high processor speed, which is not conducive to reducing power consumption.

The edge timing method decodes the data bits by measuring the time between edges, however it was discounted as it is overly complex.

Mr Sim also discussed a synchronous logic solution, which combines edge detection and sampling. The process is shown in Figure 3.10:

Figure 3.10 - Synchronous logic decoding process

This solution was originally discounted as a possible solution, due to additional external hardware requirements. However, it is in fact is a simplified version of Sim’s over-sampling method [1], and is easily implemented in software using a capture/compare module.

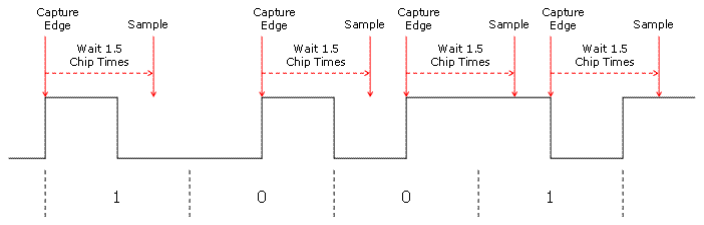
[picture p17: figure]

Figure 3.11 - Edge capture / sampling timing diagram

As can be seen in Figure 3.11, even if the clock is initially incorrectly detected, it will be correctly acquired as soon as the data bit changes from 1 to 0, or 0 to 1. This supports the assertion that the preamble would have to consist of alternating data bits, i.e. 0xAA or 0x55 [1].

A disadvantage of this method is that the second chip of each bit is not verified. However, this should not pose a problem; the effect of any interference would be to disrupt the clock rather than corrupt the data, and any data errors that do occur will be detected by the frame’s CRC.

3.3.3.2 Clock Detection

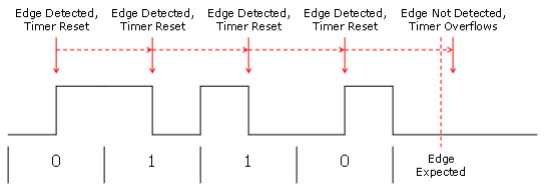
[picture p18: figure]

Figure 3.12 - Clock Detection Timing Diagram

A desirable additional feature is to be able to detect whether a valid clock signal is present. This would provide a more reliable alternative to the carrier detect pin of the X2010 transceiver, which is severely afflicted by noise (Figure 3.8, Figure 3.18). This is easily implemented by detecting the delay between clock edges, which should be no more than 2 chip times. Each time a clock edge is detected, a “watchdog” timer is set to overflow in 2.2 chip times, which allows for a clock rate tolerance of 10%. If the clock edges cease for more than 2.2 chip times, the timer will overflow, causing an interrupt (Figure 3.12). The advantage of this approach is that it only incurs an overhead of 6 instruction cycles for each clock period (to reset the timer), as no additional processing is required unless the clock is actually lost.

It is expected that random noise pulses may occasionally be detected as a valid clock signal, thus both the following conditions must be met to detect valid data:

1. At least 8 consecutive clock pulses have been detected.
2. Either:
a. The shift register contains a preamble byte.
b. The start of frame has been detected.

Therefore, the valid data flag will only be asserted by a valid preamble followed by a start of frame sequence and frame body.

3.3.3.3 Frame Synchronisation

3.3.3.3.1 Start of Frame Sequence Detection

The current mechanism for detecting the start of each frame is to prefix each frame with several preamble bytes, followed by a single start of frame (SOF) byte. When the receive buffer contains three preamble bytes and one SOF byte, the start of the frame is detected.

However, without start and stop bits, the receiver will not initially be synchronised to the start of each byte, thus the start of the frame cannot be detected by simply decoding the preamble and SOF bytes.

Initially, the data bits are shifted into a 16-bit shift register as they are decoded. Each time a data bit is received, the contents of the shift register are checked; if it contains one preamble byte followed by one SOF byte, the start of frame is detected. Once this occurs, the receiver is synchronised to the start of the first data byte, and can commence decoding bytes normally.

As mentioned previously, the preamble byte should consist of alternating bits to ensure synchronisation, i.e. 10101010. The Ethernet protocol uses 10101011 as a start of frame byte, however since this technique only checks 16 bits of data, the SOF byte should be as different as possible from the preamble byte. For Manchester encoded data, this would be consecutive ones or zeros, i.e. 0xFF or 0x00.

Figure 3.13 - Start of Frame Detection

3.3.3.3.2 Detecting the End of Frame

The current method for detecting the end of each frame is to use an end of frame (EOF) character. However, this prevents the use of the EOF character within the body of the frame, which cannot be enforced when the frame contains user data. Other protocols solve this problem using bit-stuffing techniques. However, it would be preferable to avoid such complexities in this project.

An alternative approach is to include the frame length as part of the header of each frame. The problem with this approach is that the frame length cannot be verified by the CRC until the entire packet has been received. However, consider the consequences of an erroneous frame length value:

1. If the received frame length is less than the actual frame length, the receiver will terminate reception prematurely, causing the CRC check to fail.
2. If the received frame length is more than the actual frame length, the receiver will continue receiving after the frame ends. This may have two outcomes:
a. The receiver will be reset when it detects that the clock is no longer present, and the frame will be discarded as if it were incomplete.
b. If for any reason a clock is still present, decoding will continue until the receive buffer is full, and the additional bytes will cause the CRC check to fail.

### 3.3.4 Software Buffers

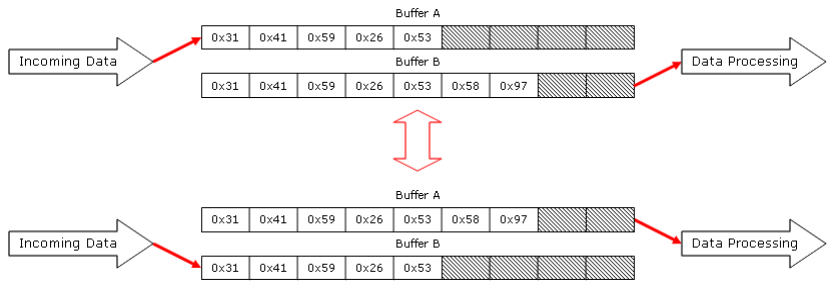
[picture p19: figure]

Figure 3.14 - Popcorn Buffering

Data buffering is an important part of the encoding and decoding processes. The current software only provides one buffer each for transmission and reception, which precludes simultaneous data communications and processing. That is, when a packet has been received, the next packet cannot be received until the previous one has been processed.

One technique used to allow simultaneous data processing and reception is known as popcorn buffering. This comprises two identical buffers, one used for reception, and one used for processing. Once a frame has been processed, and the next one fully received, the buffers are switched (Figure 3.14). This technique is also equally applicable to data transmission.

This switchover should ideally be transparent to the receiving and processing algorithms, thus a portable data structure is required to represent the buffers. An example linear buffer data structure (Figure 3.15) consists of:

1. A contiguous block of memory which contains the buffer data.
2. An end pointer, which points to the next available memory location.
3. A cursor pointer, which points to any memory location up to the end pointer.

The Size property always has the same as the value as the End pointer, and the Length property is obtained using the scnsz assembler directive in MPASM.

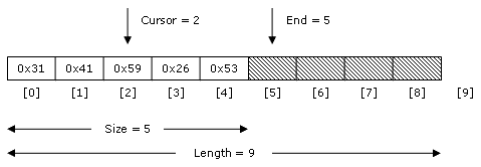
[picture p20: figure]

Figure 3.15 - Buffer Data Structure

Figure 3.16 - Buffer Data Structure Memory Map

The data memory block, end pointer, and cursor pointer are all stored in a contiguous block of memory (Figure 3.16), which means that any block of memory at least three bytes long can be used as a buffer. A particular buffer is selected by calling a macro which loads up the addresses of the buffer to FSR0 and FSR1 (Figure 3.16). The functions which may be called on this buffer include:

1. Clear the buffer.
2. Set the cursor location.
3. Get the cursor location.
4. Get the size (end) of the buffer.
5. Set the end of the buffer.
6. Write a byte at the current cursor location and increment the cursor.
7. Read a byte from the current cursor location and increment the cursor.
8. Check if the buffer is full (End == Length).
9. Check if the cursor is at the end of the data (Cursor == End).

Each of these functions is implemented as a macro, which manipulates the buffer using FSR0 and FSR1.

### 3.4 MEDIA ACCESS CONTROL

As concluded in the literature review, the power save component of the MAC protocol should implement a schedule consisting of alternating “high traffic” and “low traffic” periods. Preamble sampling is to be implemented during the low traffic period, with adaptive techniques used to optimise power savings for anticipated network traffic. The preamble sampling technique will be modelled, discussed, and optimised for static network parameters. Techniques for adaptively reconfiguring the protocol will be discussed and developed, including synchronising schedules across the network. This will be concluded with a discussion of techniques for media contention and collision management.

### 3.4.1 Preamble Sampling

Recall that in preamble sampling, nodes periodically wake up and sample the medium for activity; nodes remain awake if a preamble is detected, otherwise return to sleep (Figure 2.5). The preamble is the same length as one sampling cycle, which guarantees that it will be detected by all neighbouring nodes irrespective of their relative phases.

The energy required to transmit and receive the extended preamble partially offsets the power savings made during the sleep intervals, and also increases the probability of collisions due to increased packet length. Therefore, the energy saving provided by this technique will be dependent on the chosen sleep interval, as well as the network conditions and hardware specifications. A model will be developed, which can be used to determine the optimal sleep interval and maximum energy savings for a particular scenario.

There are other performance metrics which are also affected by the sleep interval, such as packet latency; however these are not of primary importance and thus shall not be analysed.

3.4.1.1 Modelling and Optimisation

The following set of parameters describes the preamble sampling technique, characteristics of the nodes, and network conditions:

1. The sleep interval, i.e. the time between each sample, t (seconds).
2. The power-up delay of the transceiver, i.e. the time required by the receiver to provide a valid RSSI reading, TPWUP (seconds).
3. The time required to assess the channel, i.e. the time required by the microprocessor to perform an A/D conversion on the RSSI signal, TA/D (seconds).
4. The listen interval, T = TPWUP + TA/D (seconds).
5. The power consumed whilst the node is transmitting, Pt (Watts).
6. The power consumed whilst the node is receiving, Pr (Watts).
7. The average number of packets transmitted per second, f (Hz).
8. The average number of nodes affected by each transmission, n, which is dependent on the network density.

The model will predict the average power saving per node for these parameters, which as opposed to total power consumption allows the removal of parameters such as baud rate and packet length. Other performance metrics, such as throughput and latency will not be modelled, as they are of secondary importance to power consumption. For now, the effects of packet collisions are ignored to simplify the model, as collisions are relatively unlikely in a sparse low traffic network. Collisions and subsequent retransmissions could be incorporated into the mode by defining a new parameter, actual packet rate f’ (t, l, n, f), i.e. a variable dependent on the preamble length, packet length, node density, and packet rate.

The approximate average power consumption for an idle node is given by:

[Watts] saving | Pr tT
P | ⎟

⎠ ⎜

⎝ + = | t ⎞⎛ | . | (3.2)

The additional energy required to transmit the preamble is given by:

[Joules] transmit | t = tPE | . | (3.3)

Assuming that on average each node will wake up halfway through the preamble, the additional energy required to receive the preamble is given by:

[Joules] 2

r
receive
tP E | = | . | (3.4)

Therefore, the net power saving per node is given by:

( | EEfPP | ) [Watts] net = saving − | transmit + receive | . | (3.5)

[Watts] 2 ⎟
⎠

⎞ ⎜
⎝
⎛ ⎟ | +− ⎠
⎞ ⎜
⎝

⎛
− = | r
net | r | t

tP ntPfP tT
t P | . | (3.6)

Optimising this equation for the largest power saving gives the following expression for the optimal value of t:

[Seconds] 2(

2 | T
nPPf

TP
t

rt

r | − + = | . | (3.7)

The net power saving given in Eq. (3.5) is plotted against sleep interval for several different network densities and packet rates in Figure 3.17. The definitions of the various traffic rates used are presented in Table 3.1, and the fixed parameters derived from data sheets [4, 38], are presented in Table 3.2.

Table 3.1 - Classification of traffic rates

Traffic Rate | Packet Rate (Hz)
Low | 1/1800
Medium | 1/60
High | 1

Table 3.2 - Hardware Parameters

Parameter | Value | Derivation
T | 1.05 ms | TPWUP = 1 ms [4] TA/D = 50 μs [39]
Pt | 215 mW | Iq(VGA) = 35mA [38] Itx(X2010) = 8mA [4] Vcc = 5V
Pr | 35 mW | Irx(X2010) = 7mA [4] Vcc = 5V

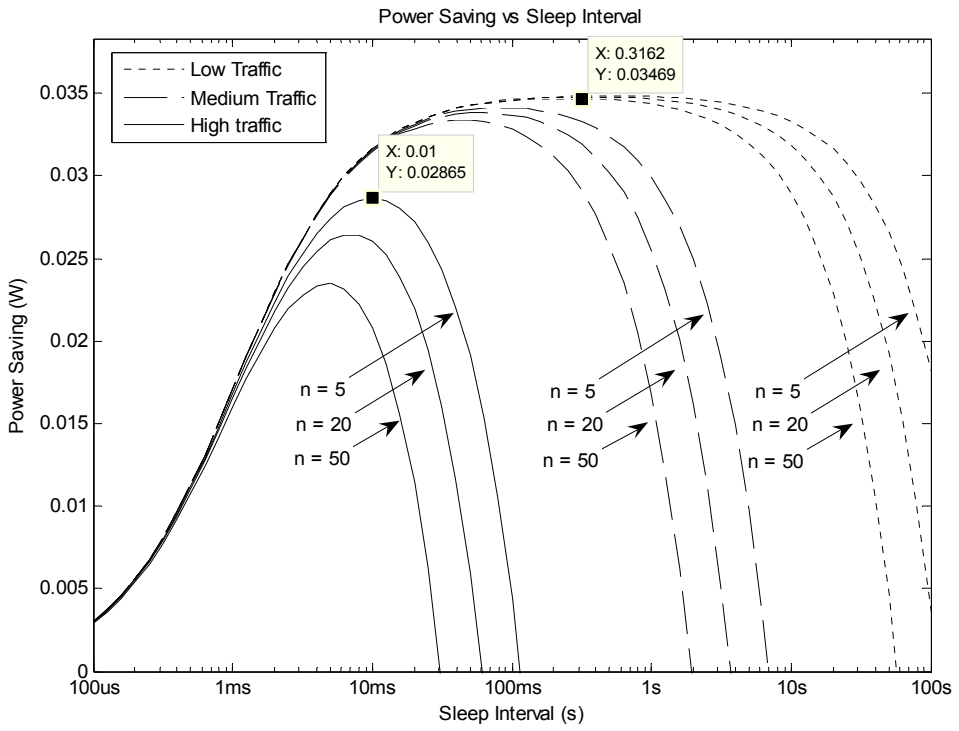
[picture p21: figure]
Power Saving (W); Power Saving vs Sleep Interval; Sleep Interval (s); Low Traffic; Medium Traffic High traffic

Figure 3.17 - Power Saving vs. Sleep Interval

Note in Figure 3.17 that the both the optimal sleep interval and potential power savings are highly dependent on the amount of network traffic. Also note that the saving is increased for lower values of n, thus this technique is well suited to sparse networks.

Without preamble sampling, the idle power consumption of the radio is 35 mW (Table 3.2). However, with preamble sampling, a power saving of up to 34.69mW is possible, thus the power consumption per node is a mere 310 μW, plus the power consumption of transmitting packet bodies. Even with a high traffic rate, a power saving of 28.65 mW is possible. However the actual power savings would be slightly less, due to a higher of probability packet collisions and subsequent retransmission.

3.4.1.2 Dynamic Reconfiguration

As discussed in Section 2.1.7 (p. 14), the power save protocol will extend the preamble sampling concept, by including both scheduled and adaptive reconfiguration to optimise the sleep interval for the anticipated traffic rate.

3.4.1.2.1 Scheduled Reconfiguration

Bulk data transfer will be constrained to brief intervals which occur at predetermined times, thus an optimised reconfiguration can be scheduled for these periods. Section 2.1.7 (p. 14) discussed defining these “high traffic” periods so that all nodes are continuously awake for the entire period. However, not all parts of the network will be active at all times during this period. Therefore, rather than all nodes being continuously awake, it may in fact be more energy efficient to optimise the preamble sampling technique for the higher traffic rates. The optimal sleep interval would have to be calculated beforehand at the application layer, based on the amount of traffic anticipated during the high traffic period. However, depending on the actual traffic rate, it may actually be more energy efficient for nodes to not sleep during this period. This is especially true considering the increased probability of collisions.

3.4.1.2.2 Adaptive Reconfiguration

During network operations such as address allocation, replies from neighbouring nodes will cause a period of localised high traffic immediately after the request. By providing an interface for higher level protocols to dynamically reconfigure the MAC layer, the sleep interval can be optimised based on this anticipated traffic. The network layer header will include a “high traffic timer” field indicating how long, if at all the source node will remain active for, so that neighbouring nodes can use a shorter preamble for packets it sends to that node.

Note that this technique is particularly effective for broadcast requests such as address allocation and route discovery, as every neighbouring node makes a power saving, whilst only the requesting node consumes more power.

### 3.4.2 Schedule Synchronisation

The dynamic preamble scheduling scheme presented in the previous section provides a good mechanism to optimise power savings during anticipated high traffic periods, and maintains network connectivity during low traffic periods at a higher transmission energy cost. However, a mechanism is needed to allow the traffic schedule to be globally synchronised. Three such mechanisms shall be discussed:

1. An active synchronisation mechanism which is propagated globally and initiated by a single node.
2. A phase discovery and correction mechanism which counters the effects of clock drift.
3. A synchronisation request mechanism which allows nodes to resynchronise if they believe they are completely out synchronisation with the rest of the network.

3.4.2.1 Active Synchronisation

Although an ad hoc sensor network is by definition infrastructure-less, there will be a sink node which all sensors periodically transfer their data to. The sink node will likely be permanent, and hence is a logical point to initiate active synchronisation operations from.

The active synchronisation operation will commence with the sink node broadcasting a synchronisation message, which includes the value of its clock at the exact time the message was transmitted (as opposed to the time when the message was queued for transmission). Nodes which receive this message will update their clocks, and set a timeout during which they will ignore all synchronisation messages. They will then rebroadcast the message and include the exact time that they transmitted the message. Synchronisation messages will use the longer preamble so that they will be received by neighbouring nodes regardless of which traffic mode they are in.

A likely traffic schedule would be 5 minutes of high traffic followed by 6 hours of low traffic, hence timing will be performed by a real time clock chip, which has a precision of one second. Because the DS1305 real time clock chip [35] resets its internal counter when the seconds register is written, even in the absence of any delays there will be a lag error of up to one second with each hop. Assuming the values of the RTC chips’ internal counters are random and uniformly distributed, the average lag will be 0.5 seconds per hop. Considering that the propagation and processing delays will add to this error, the absolute value of the error can be reduced by adding one second to the clock value each time a synchronisation message is broadcast.

3.4.2.2 Phase Discovery and Correction

Consider the high traffic period to be divided into one second slots. The network header for each packet transmitted during the scheduled high traffic period includes the number of the slot it was transmitted in with respect to the source node. This information allows neighbouring nodes to calculate the relative phase of their clock schedules with a precision of one second, and if necessary adjust their schedule to counter the effects of clock drift.

This concept of phase discovery and adjustment is similar to that used in [9]. However, in this case the phase information is piggybacked onto regular packets, and hence incurs minimal overhead.

3.4.2.3 Synchronisation Request

Immediately after a node joins the network and is allocated an address, it should request synchronisation from its neighbours using the low traffic preamble, so that it may synchronise to the global traffic schedule. This should also be performed if a node otherwise believes it has completely lost synchronisation with the rest of the network, e.g. if it did not detect any activity during the last high traffic period.

### 3.4.3 Media Contention and Collision Management

In 2004, Sloots [2] developed a Carrier Sense, Multiple Access protocol with exponential backoff. Before a frame is transmitted, the CD pin of the transceiver is tested to check if the media is free. If the media is busy, the node generates a timeout with exponential backoff:

Timeout = 0.5s × 2n | (3.8)

Where n is the number of times the node has tried to transmit. When n reaches a predetermined retry limit, the transmission is abandoned.

There are two problems with this protocol which will be addressed in the following sections.

3.4.3.1 Fixed Backoff Period

The first problem is that the initial timeout period is fixed at 0.5 seconds. If two nodes unsuccessfully attempt to transmit at the same time, their subsequent retries will also coincide, causing repeated collisions. The Ethernet protocol has dealt with this problem by randomising the timeout according to the formula:

Timeout = k × rand() × 2n | (3.9)

Where k is the slot time, and rand() is a random number between 0 and 1. A random number can be quickly generated by taking the CRC, which is pseudo-random for each packet, and XORing it with TIMER3, which is pseudo-random for each retry. This number will then be truncated using a bit mask, to limit the maximum timeout to k × 2n

3.4.3.2 Clear Channel Assessment

The second problem is that any noise present on the transceiver frequency may be incorrectly be demodulated as a valid carrier, which has previously been noted by Sloots [2].

This theory was tested by observing the voltage on the active low carrier detect (/CD) line with no signal present. When a signal is present, the /CD voltage is stable at 0V. However, when a ¼ Wavelength antenna is connected with no signal present, the transceiver detects significant amounts of noise as a valid carrier (Figure 3.18).

As can be seen in Figure 3.18, the /CD voltage regularly drops below 0.8V (TTL logic low), which would cause the node to incorrectly detect that a carrier is present. There are several alternatives to using the /CD line to detect if a valid signal is present:

1. Low pass filter the /CD line, and perform an A/D conversion on it. If the result is more than zero, then there is no valid signal present.
2. Perform an A/D conversion on the RSSI line. If the result is less than the noise floor, then there is no valid signal present.
3. Use the clock detect flag as an indicator of whether a valid signal is present.

Figure 3.18 - Carrier Detect (Active Low), No signal present, 5V/div, 1ms/div

### 3.5 ADDRESS ALLOCATION

As discussed in section 2.2.6 (p. 28), the address protocol for this protocol shall be based on the concept of address spaces, and attempt to incorporate the salient features of both [23, 31]. The improvements made to [23] can be summarised as follows:

1. A requesting node does not accept the first address offer it receives. Instead, it waits for all replies to arrive, then accepts the largest offer (from [31]). This promotes more even distribution of available addresses throughout the network.
2. When a requesting node receives several offers from neighbouring nodes, it does not explicitly reject each individual offer it did not accept. Instead, a single broadcast message is used to accept the successful offer, which implicitly rejects all other offers. This significantly reduces the number of messages required to complete an address allocation operation.
3. The network will not be flooded with an address search message unless the first address request is unsuccessful. This is achieved by including a retry number in the request message, allowing recipients of the message to determine how many unsuccessful requests have been made. This prevents unnecessarily flooding the network with an address search message.

The operation of this protocol is described in the following sections.

### 3.5.1 Network Setup

For this network event, the protocol is identical to Tayal and Patnaik [23]. When the very first node starts up, it will broadcast an AREQ (address request message), and wait for a reply (Figure 3.19). Since there are no other nodes in the network, it will not receive any replies, and will rebroadcast the AREQ message AREQ_RETRY_LIMIT times. After this time it will conclude that it is not in range of an existing network, and create a new network by taking possession of the entire address space.

### 3.5.2 Node Join

When a node starts up, it will enter the INIT (initialisation) state and assume the address 0x00, which is designated as an anonymous address for initialising nodes. Since the node does not have a MAC address, it randomly generates an 8-bit unique id (UID) to distinguish it from other nodes which are simultaneously initialising. The node will broadcast an AREQ message, and wait for replies from neighbouring nodes (Figure 3.19).

Neighbouring nodes which receive this message will check if they have any available addresses. If a node has spare addresses, it will enter the ALLOC (allocation) state, and mark half of its address space as under allocation. It will then send an AREP (address reply message) indicating the address range it is willing to allocate (Figure 3.20).

Two distinct cases may arise from this scenario.

1. At least one neighbouring node has available addresses, and sends an AREP message to the requesting node (Local Allocation).
2. There are no neighbouring nodes with available addresses. The requesting node receives no replies, and hence rebroadcasts the AREQ message. Neighbouring nodes receive the second request and infer that the first request failed, so they initiate a global address search.

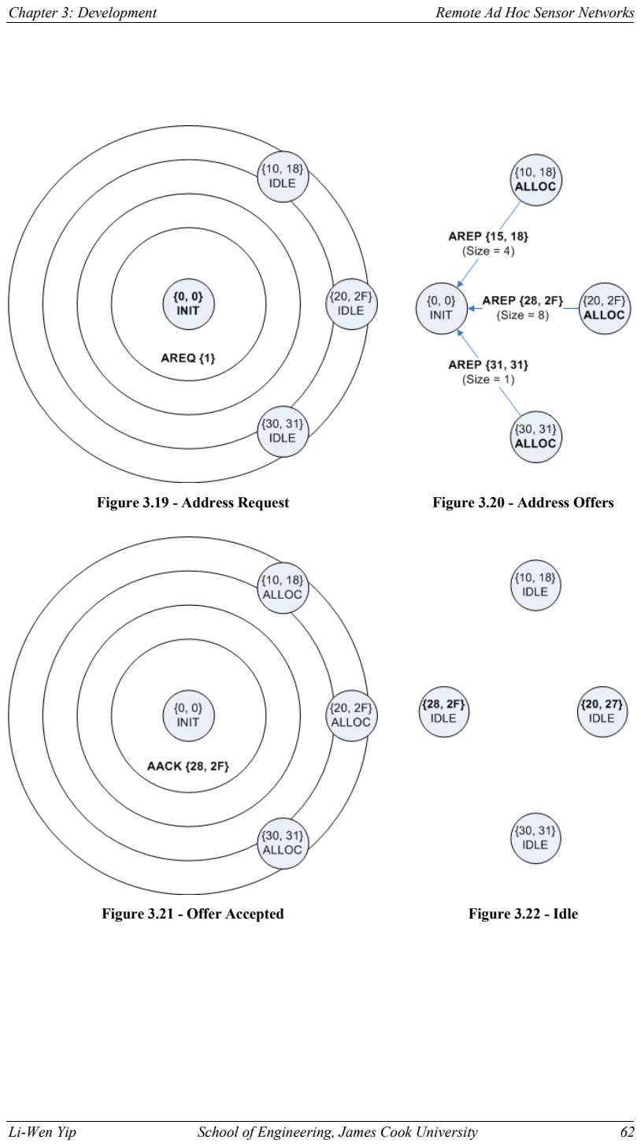
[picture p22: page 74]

Figure 3.19 - Address Request | Figure 3.20 - Address Offers
Figure 3.21 - Offer Accepted | Figure 3.22 - Idle

### 3.5.3 Local Allocation

In this case, the requesting node does not immediately reply to any AREP messages it receives, rather it caches them until a timeout expires (Figure 3.20). This timeout is set so that the requesting node has the opportunity to receive replies from all its neighbours before deciding which offer to accept. This feature promotes a more even distribution of addresses throughout the network, as implemented in ZAL [31].

Once the reply timeout has expired, the requesting node will broadcast an AACK (address accept message) indicating which offer it is about to accept (Figure 3.21). It will take possession of the largest address space it was offered, and enter the IDLE state (Figure 3.22).

Assuming all allocating nodes received the AACK message, the node whose offer was accepted will delete its addresses under allocation, whilst all other nodes will repossess their address under allocation (Figure 3.22). Note in [23] that the requesting node unicasts an AREJ (address reject message) to every node whose offer it did not accept. In this protocol the rejection is implicit, significantly reducing the number of transmissions required to complete the operation.

### 3.5.4 Global Address Search

A global address search will be initiated when a node receives an address request with a retry number of two or higher, and does not have any available addresses. Firstly, it will send a negative reply to the requesting node to acknowledge that it has received the request. Secondly, it will broadcast an ASRCH (address search) message. Nodes which receive this message and have available addresses will send an address reply back to the requesting node. The requesting node will reply with either an AACK or an AREJ. Nodes which do not have available addresses will send a negative reply back to the requesting node, rebroadcast the ASRCH message, and ignore all future ASRCH message originating from the same node. In this way, the ASRCH message will be flooded throughout the network until an available address space is found.

[23] Does not specify how remote nodes are able to route their replies back to the requesting node, and vice versa. Here are two techniques that could be used to achieve this:
1. Each ASRCH message includes a route back to the requesting node (Figure 3.23). Therefore, each time a node broadcasts an ASRCH message it appends its own address to this route. This technique is used in [27]. A disadvantage of this technique is that in a large and sparse network, the address list could get quite long, introducing additional overhead into the operation.
2. When a node broadcasts an ASRCH message, it enters a proxy state, in which it forwards all AREP and NREP messages back toward the requesting node. In this way, a well-defined connection is formed between the requesting and allocating nodes. However, each proxy node only knows about the next node in the route, thus routing information is not needed in the reply messages. This is very similar to the DSR adaptation developed by Steven Sloots [2]. This technique introduces an opportunity to reduce the amount of traffic sent back to the requesting node: If a proxy node receives two positive replies, it can reject the smaller offer locally, and only send the larger offer back to the requesting node. The disadvantage of this technique is its complexity.

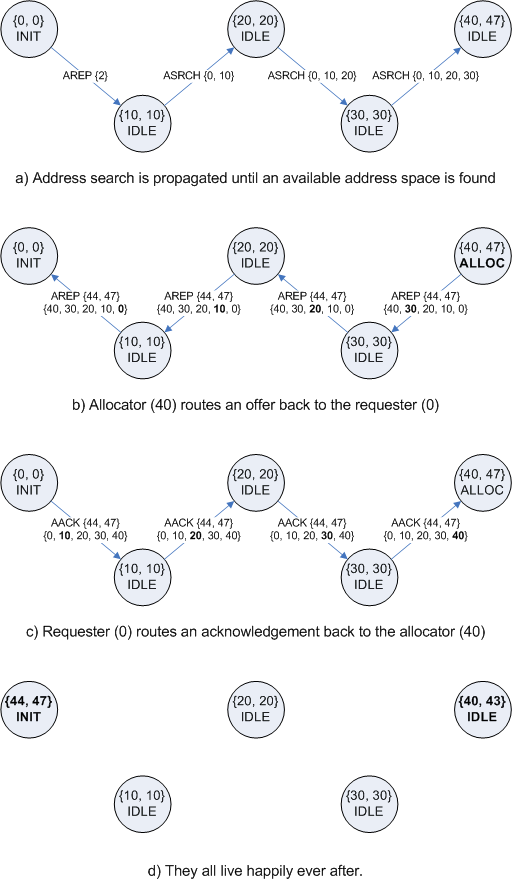
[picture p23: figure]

Figure 3.23 - ASRCH message contains a routing information

Chapter 4: Implementation and Testing | Remote Ad Hoc Sensor Networks

Chapter 4

## IMPLEMENTATION AND TESTING

### 4.1 HARDWARE PLATFORM

### 4.1.1 Node PCB Design and Construction

The hardware designed for this project was based on the hardware designed by Steven Sloots [2] in 2004 (Figure 3.1, p29), with the major modifications listed below:

1. The VGA bypass relay was replaced with an ADG918 CMOS switch [34].
2. An emitter follower voltage to supply the ADG918 with 2.75 Volts.
3. A DS1305 Real Time Clock Chip [35] added to the microcontroller’s SPI bus.
4. An RC network to reduce the noise on the X2010 transceiver’s RSSI line.
5. An RJ12 socket enabling compatibility with the Microchip ICD2.

Although the same component interconnections were retained, the PCB was completely redesigned to accommodate the additional hardware, with an emphasis on features which would assist debugging and modifications to both hardware and software. Some of these features include:

1. Strict rules for track sizes, which allows easy identification of power tracks and RF tracks.
2. Easily accessible test points for transceiver data pins and power rails.
3. Additional status LEDs and a power indicator LED.
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

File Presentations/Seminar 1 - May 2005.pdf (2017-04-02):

# Reef Ad Hoc Sensor Network

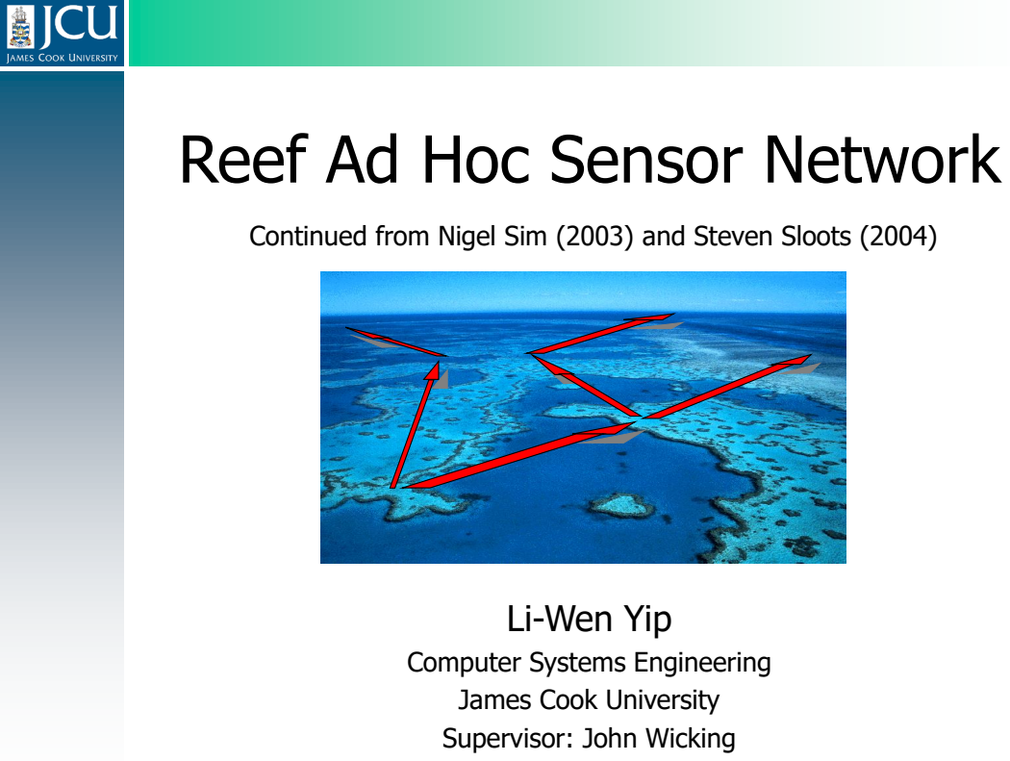
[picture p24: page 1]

Continued from Nigel Sim (2003) and Steven Sloots (2004)

Li-Wen Yip

Computer Systems Engineering
James Cook University
Supervisor: John Wicking

# Summary

## - Ad-hoc networking overview - Problem Overview - Previous work - Project Scope - Literature Review - Progress - Outcomes - Questions

# Ad Hoc Networks

Main Entry: ad hoc
Function: adjective

### 1 a : concerned with a particular end or purpose

b : formed or used for specific or immediate problems or needs <ad hoc solutions>
2 : fashioned from whatever is immediately available

Source: Merriam Webster Online Dictionary – www.m-w.com

In computer networking, ad-hoc is a connection method for wireless networks that requires no base station — devices discover others within range to form a network for those computers.

Source: Article on “ad hoc” at en.wikipedia.org

# What is an Ad-Hoc Sensor Network?

- Independent nodes forming a
distributed sensing network.
- Self-configuring
- No fixed infrastructure or topology
- Nodes contain
– Battery
– Radio
– Sensors
– Microprocessor
- Static nodes
- Low data rate
- QoS not important
- Existing solutions:
– Berkley Smartdust
– Crossbow Motes

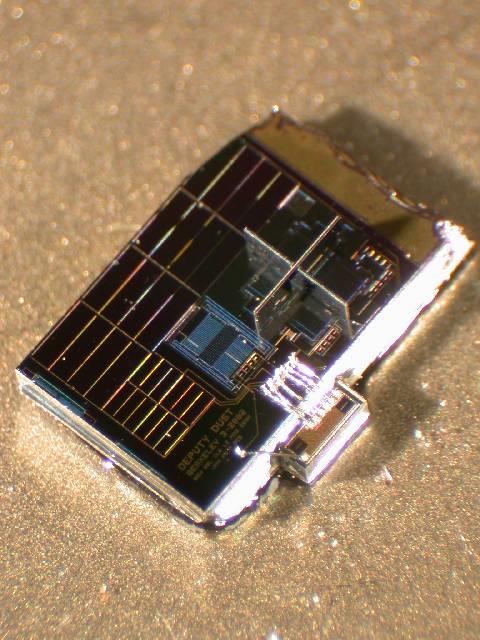
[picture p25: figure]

Image Source: http://www-bsac.eecs.berkeley.edu/archive/users/warneke-brett/SmartDust/

# Berkley Motes

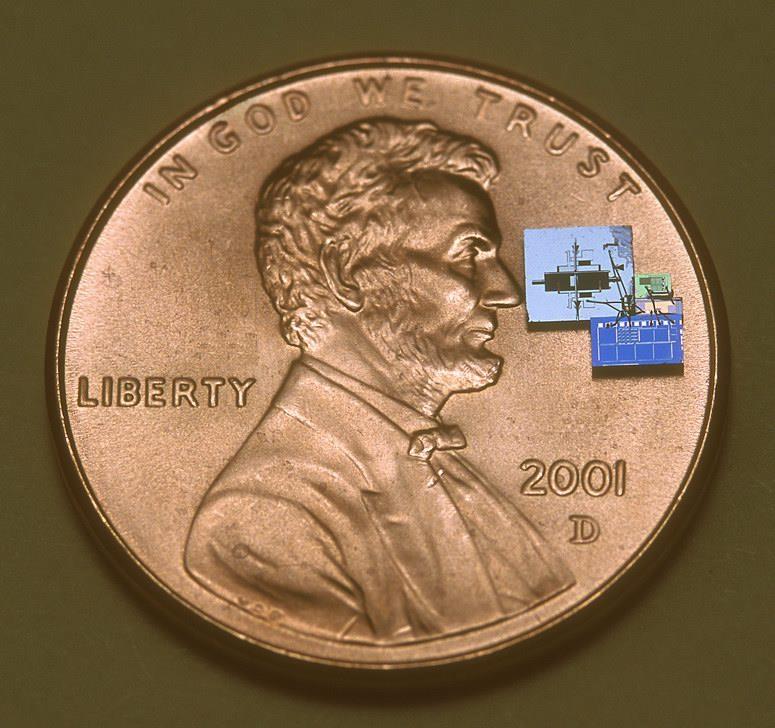
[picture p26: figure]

Image Source: http://www-bsac.eecs.berkeley.edu/archive/users/warneke-brett/SmartDust/

# AIMS Reef Monitoring Network

## - Monitoring Stations - Data collection

– long-range radio links
– manual visits.

## - Replace with ad hoc

sensor network.

## - Reduce

– power consumption
– maintenance.


Image Source: “Sensor Networking the Great Barrier Reef”, Kininmonth et al, AIMS Tsv QLD.

# Multi-Hop Power Savings

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

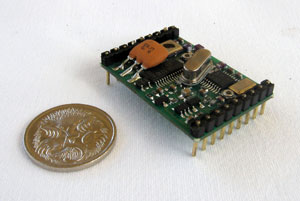
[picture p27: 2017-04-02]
docs/images/hardware/x2010-small.jpg

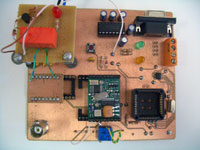
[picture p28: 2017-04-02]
docs/images/hardware/sloots.jpg

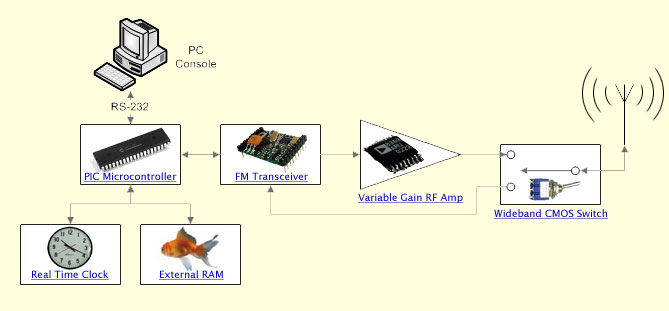
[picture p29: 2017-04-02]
docs/images/hardware/block-diagram.jpg

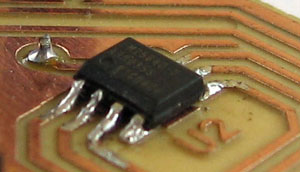
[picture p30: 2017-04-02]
docs/images/hardware/fm25c160-small.jpg

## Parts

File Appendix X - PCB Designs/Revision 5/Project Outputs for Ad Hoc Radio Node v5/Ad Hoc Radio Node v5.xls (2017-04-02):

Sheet: Ad Hoc Radio Node v5
Description | Designator | Footprint | LibRef | Quantity | Value
Capacitor | C1 | 0.1 ELECTRO CAP | Cap2 | 1 | 22uF
Capacitor | C2 | 0.1 ELECTRO CAP | Cap2 | 1 | 22uF
Capacitor | C3 | 0.1 CERAMIC CAP | Cap | 1 | 0.1uF
Capacitor | C4 | 0.1 ELECTRO CAP | Cap2 | 1 | 22uF
Capacitor | C5 | 0.1 ELECTRO CAP | Cap2 | 1 | 22uF
Capacitor | C6 | 0.1 CERAMIC CAP | Cap | 1 | 0.1uF
Capacitor | C7 | 0.1 Ceramic Cap | CAP | 1 | 0.1uF
Capacitor | C8 | 0.1 CERAMIC CAP | Cap | 1 | 22pF
Capacitor | C9 | 0.1 CERAMIC CAP | Cap | 1 | 22pF
Capacitor | C10 | 0.1 CERAMIC CAP | Cap | 1 | 0.1uF
Capacitor | C11 | 0.1 ELECTRO CAP | Cap2 | 1 | 1uF
Capacitor | C12 | 0.1 ELECTRO CAP | Cap2 | 1 | 1uF
Capacitor | C13 | 0.1 ELECTRO CAP | Cap2 | 1 | 1uF
Capacitor | C14 | 0.1 ELECTRO CAP | Cap2 | 1 | 1uF
Capacitor | C15 | 0.1 ELECTRO CAP | Cap2 | 1 | 1uF
Capacitor | C16 | 0.1 CERAMIC CAP | Cap | 1 | 0.1uF - Ceramic
Capacitor | C17 | 0.1 CERAMIC CAP | Cap | 1 | 0.1uF
Capacitor | C18 | 0.1 CERAMIC CAP | Cap | 1 | 0.1uF
Capacitor | C19 | 0.1 CERAMIC CAP | Cap | 1 | 0.1uF
Capacitor | C20 | 0.1 CERAMIC CAP | Cap | 1 | 0.1uF
Default Diode | D1 | diode-0.4/1.8 | Diode | 1 | 1N914
Right Angle, Ultra Low Profile PCB Jack, Unshielded Version | J10 | JACK1.27-2H6 | 43202-6101 | 1
Header, 4-Pin | JP1 | 4 Way Terminal Block | Header 4 | 1
 | JP3 | JUMPER-0.4 | JUMPER | 1
 | JP4 | JUMPER-0.4 | JUMPER | 1
 | JP5 | JUMPER-0.4 | JUMPER | 1
 | JP6 | JUMPER-0.4 | JUMPER | 1
 | JP7 | JUMPER | JUMPER | 1
Receptacle Assembly, 9 Position, Right Angle | JP8 | DSUB1.385-2H9 | D Connector 9 | 1
Typical RED, GREEN, YELLOW, AMBER GaAs LED | LED1 | Std LED | LED2 | 1
Typical RED, GREEN, YELLOW, AMBER GaAs LED | LED2 | Std LED | LED2 | 1
Typical RED, GREEN, YELLOW, AMBER GaAs LED | LED3 | Std LED | LED2 | 1
Typical RED, GREEN, YELLOW, AMBER GaAs LED | LED4 | Std LED | LED2 | 1
Typical RED, GREEN, YELLOW, AMBER GaAs LED | LED5 | Std LED | LED2 | 1
 | P1 | PCB BNC Connector | PCB BNC CONNECTOR | 1
NPN Bipolar Transistor | Q1 | bjt | NPN | 1
Resistor | R1 | AXIAL-0.3 | Res1 | 1 | 0
Resistor | R2 | AXIAL-0.3 | Res1 | 1 | 0
Resistor | R3 | AXIAL-0.3 | Res1 | 1 | 0
Resistor | R4 | AXIAL-0.4/1.8 | Res1 | 1 | 5K
Resistor | R5 | AXIAL-0.4/1.8 | Res1 | 1 | 1K
Resistor | R6 | AXIAL-0.4/1.8 | Res1 | 1 | 1K
Resistor | R7 | AXIAL-0.4/1.8 | Res1 | 1 | 1K
Resistor | R8 | AXIAL-0.4/1.8 | Res1 | 1 | 1K
Resistor | R9 | AXIAL-0.4/1.8 | Res1 | 1 | 1K
Resistor | R10 | AXIAL-0.4/1.8 | Res1 | 1 | 1K
Resistor | R11 | AXIAL-0.4/1.8 | Res1 | 1 | 1K
Resistor | R12 | AXIAL-0.4/1.8 | Res1 | 1 | 1K
Potentiometer | R13 | VARIABLE RESISTOR | RPot1 | 1 | 20k
Switch | RST | RESET SWITCH | SW-PB | 1
Test Point | TP1 | TESTPOINT | TESTPOINT | 1
Test Point | TP2 | TESTPOINT | TESTPOINT | 1
Test Point | TP3 | TESTPOINT | TESTPOINT | 1
Test Point | TP4 | TESTPOINT | TESTPOINT | 1
Test Point | TP5 | TESTPOINT | TESTPOINT | 1
Test Point | TP6 | TESTPOINT | TESTPOINT | 1
Test Point | TP7 | TESTPOINT | TESTPOINT | 1
 | U1 | PLCC 44-Way IC Socket | PIC18C452_PLCC | 1 | PIC18C452
 | U2 | SOP-8 | FRAM | 1 | FM25640-S
 | U3 | DIP-16 | DS1306 | 1 | DS1306
+5V Powered RS-232 Driver/Receiver | U4 | DIP-16 | MAX232EPE | 1 | MAX232EPE
 | U5 | ad8639 carrier board | AD8369_DIGITAL_CONT_PWR_AMP | 1 | AD8369
 | U6 | DIP-8 | ADG918 | 1 | ADG918
 | U7 | X2010 | NBFM_TRANSCEIVER | 1 | X2010
Series 3-Terminal Positive Regulator | U8 | SFM-T3/A4.7V | LM340T5.0 | 1 | LM7805
Series 3-Terminal Positive Regulator | U9 | SFM-T3/A4.7V | LM340T5.0 | 1 | LM7805
Crystal Oscillator | Y1 | XTAL | XTAL | 1 | 4MHz
Crystal Oscillator | Y2 | watch crystal | XTAL | 1 | 32.768kHz

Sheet: Sheet1
Description | Qty | Manfacturer | Mfg Part No | Farnell Part No | Farnell Pg No | Price Ea | Price Total
LED, 3MM GREEN | 3 | KINGBRIGHT (http://au.farnell.com/jsp/endecaSearch/manufacturer.jsp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) | L-934GD | 3299480 (http://au.farnell.com/jsp/endecaSearch/partDetail.jsp?SKU=3299480&N=401) | 591 | $0.23 (http://au.farnell.com/jsp/endecaSearch/volumePricing.jsp?SKU=3299480&CNTR=) | $0.690
LED, 3MM RED | 2 | KINGBRIGHT (http://au.farnell.com/jsp/endecaSearch/manufacturer.jsp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) | L-934ID | 3350861 (http://au.farnell.com/jsp/endecaSearch/partDetail.jsp?SKU=3350861&N=401) | 589 | $0.24 (http://au.farnell.com/jsp/endecaSearch/volumePricing.jsp?SKU=3350861&CNTR=) | $0.482
TRANSISTOR, NPN TO-92 | 1 | ON SEMICONDUCTOR | BC548C | 933922 (http://au.farnell.com/jsp/endecaSearch/partDetail.jsp?SKU=933922&N=401) | 764 | 0.145 (http://au.farnell.com/jsp/endecaSearch/volumePricing.jsp?SKU=933922&CNTR=) | $0.145
RESISTOR, 0.25W 1% 1K | 6 | MULTICOMP (http://au.farnell.com/jsp/endecaSearch/manufacturer.jsp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) | MF25 1K | 543380 (http://au.farnell.com/jsp/endecaSearch/partDetail.jsp?SKU=543380&N=401) | 705 | 0.094 (http://au.farnell.com/jsp/endecaSearch/volumePricing.jsp?SKU=543627&CNTR=) | $0.564
RESISTOR, 0.25W 1% 4K7 | 1 | MULTICOMP (http://au.farnell.com/jsp/endecaSearch/manufacturer.jsp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) | MF25 4K7 | 543548 (http://au.farnell.com/jsp/endecaSearch/partDetail.jsp?SKU=543548&N=401) | 705 | 0.094 (http://au.farnell.com/jsp/endecaSearch/volumePricing.jsp?SKU=543627&CNTR=) | $0.094
RESISTOR, 0.25W 1% 10K | 2 | MULTICOMP (http://au.farnell.com/jsp/endecaSearch/manufacturer.jsp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) | MF25 10K | 543627 (http://au.farnell.com/jsp/endecaSearch/partDetail.jsp?SKU=543627&N=401) | 705 | 0.094 (http://au.farnell.com/jsp/endecaSearch/volumePricing.jsp?SKU=543627&CNTR=) | $0.188
IC, RTC 3 WIRE/SPI | 1 | MAXIM-DALLAS | DS1305 | 795987 (http://au.farnell.com/jsp/endecaSearch/partDetail.jsp?SKU=795987&N=401) | 950 | 12.140 (http://au.farnell.com/jsp/endecaSearch/volumePricing.jsp?SKU=795987&CNTR=) | $12.140
CRYSTAL, 32.768000KHZ | 1 | C-MAC FREQUENCY PRODUCTS (http://au.farnell.com/jsp/endecaSearch/manufacturer.jsp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) | A103C | 221533 (http://au.farnell.com/jsp/endecaSearch/partDetail.jsp?SKU=221533&N=401) | 959 | 2.060 (http://au.farnell.com/jsp/endecaSearch/volumePricing.jsp?SKU=221533&CNTR=) | $2.060
 |  |  |  |  |  |  | $16.363

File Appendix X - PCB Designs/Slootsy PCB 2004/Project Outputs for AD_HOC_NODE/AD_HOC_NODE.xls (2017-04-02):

Description | Designator | Footprint | LibRef | Quantity
Capacitor | C1 | 2mm Pol. Cap | Cap | 1.0
Capacitor | C2 | 2mm Pol. Cap | Cap | 1.0
Capacitor | C3 | 5mm Tant. Cap | Cap | 1.0
Capacitor | C4 | 2mm Pol. Cap | Cap | 1.0
Capacitor | C5 | 2mm Pol. Cap | Cap | 1.0
Capacitor | C6 | 5mm Tant. Cap | Cap | 1.0
Capacitor | C7 | 5mm Tant. Cap | CAP | 1.0
Capacitor | C8 | 5.6mm Ceramic Cap | Cap | 1.0
Capacitor | C9 | 5.6mm Ceramic Cap | Cap | 1.0
Capacitor | C10 | 5mm Tant. Cap | Cap | 1.0
Polarized Capacitor (Radial) | C11 | 2mm Pol. Cap | Cap Pol1 | 1.0
Polarized Capacitor (Radial) | C12 | 2mm Pol. Cap | Cap Pol1 | 1.0
Polarized Capacitor (Radial) | C13 | 2mm Pol. Cap | Cap Pol1 | 1.0
Polarized Capacitor (Radial) | C14 | 2mm Pol. Cap | Cap Pol1 | 1.0
Polarized Capacitor (Radial) | C15 | 2mm Pol. Cap | Cap Pol1 | 1.0
Capacitor | C16 | 5mm Tant. Cap | Cap | 1.0
Capacitor | C17 | 5mm Tant. Cap | Cap | 1.0
Capacitor | C18 | 5mm Tant. Cap | Cap | 1.0
Zener Diode | D1 | DIO7.1-3.9X1.9 | D Zener | 1.0
Default Diode | D2 | DIO7.1-3.9X1.9 | Diode | 1.0
Zener Diode | D3 | DIO7.1-3.9X1.9 | D Zener | 1.0
Typical INFRARED GaAs LED | DS1 | LED | LED0 | 1.0
Typical INFRARED GaAs LED | DS2 | LED | LED0 | 1.0
Receptacle Assembly, 9 Position, Right Angle | J1 | DSUB1.385-2H9 | D Connector 9 | 1.0
Header, 4-Pin | JP1 | 4 Way Terminal Block | Header 4 | 1.0
Header, 4-Pin | JP2 | 4 Way Terminal Block | Header 4 | 1.0
BNC Elbow Connector | P1 | PCB BNC Connector - duplicate | BNC | 1.0
Resistor | R1 | AXIAL-0.3 | Res1 | 1.0
Resistor | R2 | AXIAL-0.3 | Res1 | 1.0
Resistor | R3 | AXIAL-0.3 | Res1 | 1.0
Resistor | R4 | AXIAL-0.3 | Res1 | 1.0
Resistor | R5 | AXIAL-0.3 | Res1 | 1.0
Potentiometer | R6 | VR2 | RPot2 | 1.0
Switch | S1 | Reset Switch - duplicate | SW-PB | 1.0
 | U1 | PLCC Socket 44 way | PIC18C452_PLCC | 1.0
Series 3-Terminal Positive Regulator | U2 | SFM-T3/A4.7V | LM340T5.0 | 1.0
Series 3-Terminal Positive Regulator | U3 | SFM-T3/A4.7V | LM340T5.0 | 1.0
+5V Powered RS-232 Driver/Receiver | U4 | DIP-16/X1.5 | MAX232EPE | 1.0
 | U5 | 24 pin DIP socket for TSSOP | AD8369_DIGITAL_CONT_PWR_AMP | 1.0
 | U6 | FMRRFQ1 | FMRRFQ1 | 1.0
 | U7 | FMRTFQ1 | FMRTFQ1 | 1.0
Jumper Wire | W1 | RAD-0.1 | Jumper | 1.0
Jumper Wire | W2 | RAD-0.1 | Jumper | 1.0
Jumper Wire | W3 | RAD-0.1 | Jumper | 1.0
Jumper Wire | W4 | RAD-0.1 | Jumper | 1.0
Crystal Oscillator | Y1 | XTAL | XTAL | 1.0

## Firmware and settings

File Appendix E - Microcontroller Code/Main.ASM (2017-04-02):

;******************************************************************************
;   This file is a basic template for creating relocatable assembly code for  *
;   a PIC18C452. Copy this file into your project directory and modify or     *
;   add to it as needed. Create a project with MPLINK as the language tool    *
;   for the hex file. Add this file and the 18C452.LKR file to the project.   *
;                                                                             *
;   The PIC18CXXX architecture allows two interrupt configurations. This      *
;   template code is written for priority interrupt levels and the IPEN bit   *
;   in the RCON register must be set to enable priority levels. If IPEN is    *
;   left in its default zero state, only the interrupt vector at 0x008 will   *
;   be used and the WREG_TEMP, BSR_TEMP and STATUS_TEMP variables will not    *
;   be needed.                                                                *
;                                                                             *
;   Refer to the MPASM User's Guide for additional information on the         *
;   features of the assembler and linker.                                     *
;                                                                             *
;   Refer to the PIC18CXX2 Data Sheet for additional information on the       *
;   architecture and instruction set.                                         *
;                                                                             *
;******************************************************************************
;                                                                             *
;    Filename:      Main.asm                                                  *
;    Date:          25/09/2005                                                *
;    File Version:  1.00                                                      *
;                                                                             *
;    Author:        Li-Wen Yip                                                *
;    Company:       James Cook University                                     *
;                                                                             * 
;******************************************************************************
;                                                                             *
;    Files required:         P18C452.INC                                      *
;                            18C452.LKR                                       *
;                                                                             *
;******************************************************************************
; MASTER HEADER FILE
 #include "MasterHeader.inc"


;********************************************************************************
; EXTERNAL LABELS

 #include "PHY.inc"
 #include "MAC.inc"

 #include "RTC.inc"
 #include "buffers.inc"     ; Labels for buffers.asm

; From <SoftwareTimers.asm>
 extern SWTIMERS_INIT, SWTIMERS_ISR

; From <SPI.asm>
 extern SPI_INIT

; From <RouteCache.asm>
 extern FRAM_INIT

;******************************************************************************
;Configuration bits
; The __CONFIG directive defines configuration data within the .ASM file.
; The labels following the directive are defined in the P18C452.INC file.
; The PIC18CXX2 Data Sheet explains the functions of the configuration bits.
; Change the following lines to suit your application.

;   __CONFIG    _CONFIG0, _CP_OFF_0
;   __CONFIG    _CONFIG1, _OSCS_OFF_1 & _RCIO_OSC_1
;   __CONFIG    _CONFIG2, _BOR_ON_2 & _BORV_25_2 & _PWRT_OFF_2
;   __CONFIG    _CONFIG3, _WDT_ON_3 & _WDTPS_128_3
;   __CONFIG    _CONFIG5, _CCP2MX_ON_5
;   __CONFIG    _CONFIG6, _STVR_ON_6

;******************************************************************************
;Variable definitions
; These variables are only needed if low priority interrupts are used. 
; More variables may be needed to store other special function registers used
; in the interrupt routines.

MAIN_UDATA  UDATA

WREG_TEMP   RES 1   ;variable in RAM for context saving 
STATUS_TEMP RES 1   ;variable in RAM for context saving
BSR_TEMP    RES 1   ;variable in RAM for context saving


 UDATA 0x500
swstack     RES 64

;******************************************************************************
;Reset vector
; This code will start executing when a reset occurs.

RESET_VECTOR    CODE 0x0000

    goto    Main        ;go to start of main code

;******************************************************************************
;High priority interrupt vector
; This code will start executing when a high priority interrupt occurs or
; when any interrupt occurs if interrupt priorities are not enabled.

HI_INT_VECTOR   CODE 0x0008

    bra     HighInt     ;go to high priority interrupt routine

;******************************************************************************
;Low priority interrupt vector
; This code will start executing when a low priority interrupt occurs.
; This code can be removed if low priority interrupts are not used.

LOW_INT_VECTOR  CODE 0x0018

    bra     LowInt      ;go to low priority interrupt routine



 CODE

;******************************************************************************
;High priority interrupt routine
; The high priority interrupt code is placed here.

HighInt:
    
; Check if CCP1 (Receive Clock) caused an interrupt.
_CCP1_ISR:
    btfss   PIR1, CCP1IF        ; Is the interrupt flag set?
    bra     _CCP2_ISR           ; NO - skip to checking CCP2.
    bcf     PIR1, CCP1IF        ; YES - clear it.

    btfss   PIE1, CCP1IE        ; Was the interrupt enabled?
    bra     _CCP2_ISR           ; NO - skip to checking CCP2.

    ; Let's do some decoding. Yeah Baby!
    call    MANCHESTER_DECODER  ; Call the manchester decoding routine. <PHY.asm>
    call    FRAME_DECODER       ; Call the Frame decoding routine. <MAC.asm>
    retfie  FAST                ; Done.

; Check if CCP2 (Transmit Clock / Receive Clock Watchdog) caused an interrupt.
_CCP2_ISR:
    btfss   PIR2, CCP2IF        ; Is the interrupt flag set?
    retfie  FAST                ; NO - return.
    bcf     PIR2, CCP2IF        ; YES - clear it.
    btfss   PIE2, CCP2IE        ; Was the interrupt enabled?
    retfie  FAST                ; NO - return.

    ; Check if we should run the encoder routine or the watchdog routine.
    btfss   NTXEN               ; Are we in transmit mode?
    bra     _RUN_ENCODER        ; YES

    call    CLOCK_WATCHDOG      ; NO - run the watchdog routine. <PHY.asm>
    call    RESET_DECODER       ; Notify the MAC layer clock has been lost. <MAC.asm>
    retfie  FAST                ; Done.

_RUN_ENCODER:
    ; Let's do some encoding.   
    call    MANCHESTER_ENCODER  ; Call the manchester encoding routine. <PHY.asm>
    call    FRAME_ENCODER       ; Call the frame encoding routine. <MAC.asm>
    retfie  FAST                ; Done.

;******************************************************************************
;Low priority interrupt routine
; The low priority interrupt code is placed here.
; This code can be removed if low priority interrupts are not used.

LowInt:
    movff   STATUS, PREINC2     ; Save STATUS register
    movwf   PREINC2             ; Save WREG register
    movff   BSR, PREINC2        ; Save BSR register

    call    SWTIMERS_ISR        ; <SWTimers.asm>
    call    TMR0_ISR            ; <MAC.asm>
    call    TRAFFIC_CONTROL     ; <MAC.asm>
    call    INT1_ISR            ; <MAC.asm>

    movff   POSTDEC2, BSR       ; Restore BSR register
    movf    POSTDEC2, W         ; Restore WREG register
    movff   POSTDEC2, STATUS    ; Restore STATUS register

    retfie

;******************************************************************************
;Start of main program
; The main program code is placed here.

Main:

    ; Disable interrupts during initialisation
    bcf     INTCON, GIEL        ; disable low priority interrupt.
    bcf     INTCON, GIEH        ; disable high priority interrupt.

    ; Initialisation Routines
    lfsr    2, 0x500            ; Initialise the stack
    call    SWTIMERS_INIT       ; Initialise software timers
    call    PHY_INIT            ; Initialise physical layer
    call    MAC_INIT            ; Initialise mac layer
    call    SPI_INIT            ; Initialise SPI Bus
    call    FRAM_INIT           ; Initialise FRAM chip
    call    RTC_INIT            ; Initialise RTC chip

    ; Reenable Interrupts
    bsf     RCON, IPEN          ; enable interrupt priorities
    bsf     INTCON, GIEL        ; enable low priority interrupt.
    bsf     INTCON, GIEH        ; enable high priority interrupt.


;   call    RX_ENABLE
    
;   bcf     INTCON3, INT1IE

    extern  MAC_TEST
    bra     MAC_TEST


Loopy:
    clrwdt
    bra Loopy

;******************************************************************************
;End of program

    reset   ; If we ever get here do a reset.

 END

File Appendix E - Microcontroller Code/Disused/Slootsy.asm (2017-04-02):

;Ad Hoc Radio Network
;Single Node Code
;by Steven Sloots
;for John Wicking 2004
 title "Ad_Hoc_V1"

 list p=18c452 ;Select device. 

#include <p18c452.inc> ;Include standard header file for the selected device.

;+-----------------------------------------------------------------------------------------------------------------------------------+
;| Dest. Add. (1)| Source Addr. (1) | Packet ID (1) | Tx. Pwr (1) | Route ID (2) | Hop Count (1) | Packet Info (Addresses/Data) (VAR)|
;+-----------------------------------------------------------------------------------------------------------------------------------+
;!!!!!!!!!!!!!!!!!!!!!!!!!!!!!!REMEMBER, HOP_COUNT IS INCREMENTED AS THE PACKET LEAVES!!!!!!!!!!!!!!!!!!!!!!!!!!!!!!!!!!!
;*********************************************************************
 org		0x00
	goto	device_init
 org 		0x08
	goto	IRPSERVICE
 org		0x18
	goto	LOW_PRIORITY
;*********************************************************************
	CBLOCK		0x20
;***Timing Registers***
current_rreq_timer:		1		;1 byte for timing the validity of routes
route_finder_timer: 	1		;1 byte to time the discovery of routes
backoff_timer:	1				;timer for exponential backoff CDMA algorithm
ACK_timer:		1				;timer to time the timeout on an ACK from each data packet
Reply_timer:	1
validity_count:	1
settler_count:	1
sleep_count:	1				;timer to count down to nap time
;**********************
;***Flag Registers***
error_flags:	1		;contains error flags
dsr_flags: 		1		;buffer to store the flags associated with dsr module
flag_buff:		1		;buffer to store other flags that we will use
flag_buff2:		1		;second generic flag buffer
flag_buff3:		1		;third generic flag buffer
manch_buff:		1		;buffer for flags
MAC_buff: 		1		;buffer for MAC layer related flags
timer_flags:	1		;buffer for timing related flags
tmr_on_flags:	1		;bu
;***Generic DSR Registers***
preamble_count:	1		;contains buffer flags that control layers
retry_counter: 	1		;1 byte to count retries
;ACK_requests:	1
rxbufflen:		1		;length of received bytes buffer
txbufflen: 		1		;length of packet to be sent
loadinglen:		1		;copy of txbufflen that is used to load the backup buffer
radioout_offset:1	;offset length of the byte we must transmit from the start of radioout
data_len: 		1		;length of data_bank data to be used
FSR0_H_TEMP: 	1		;to store FSR0 contents before entering sub-routine		
FSR0_L_TEMP: 	1		;ditto
highest_mem_h: 	1		;2 bytes to store the last location that we wrote a route to
highest_mem_l: 	1		;to store routing information
current_mem_h:	1		;used to track the memory location we are looking at to
current_mem_l:	1		;as above
replace_mem_l:	1		;used to mark the start of the erase procedure
replace_mem_h:	1		;as above
shuffle_buff:	1		;buffer to temorarily store the bytes from the FRAM
node_id: 		1		;This nodes ID address
latest_route_d: 1		;reg to store the latest RREQ ID
latest_route_s: 1		;reg to store the latest RREQ ID
target_addr: 	1		;Node that data packet must go to - detrermined outside this layer
RREQ_cause_addr:1
;***MAC Layer Registers***
backoff_level: 	1		;register to hold the level of back off before loading into backoff_timer
;***PARO registers***
RSSI_value: 	1		;Analog value of RSSI gained from AD conversion
tbl_RSSI_val:	1		;working register for holding the value of dB taken from lookup tables
tbl_dB_val:		1		;working register for holding the value of mW taken from lookup tables
work_dB_val:	1		;value in dB that we are working with
tbl_mW_val:		1
work_mW_val:	1
PARO_source: 	1		;the source of the packet that originated the PARO process
PARO_dest: 		1		;and the coressponding destination
Rx_power: 		1		;power level on reception
sent_power: 	1		;Power used on sending packet
reply_power:	1		;Transmission power on reply to sent packet
mod_power_A: 	1		;modified power on 1st hop
mod_A_mW:		1		;modified power for 1st hop converted to a mW reading
mod_power_B: 	1		;modified power on second hop
mod_B_mW:		1		;modified power for 2nd hop converted to a mW reading
total_init_pwr:	1		;total initial power
total_mod_pwr:	1		;total power of modified route
tbl_offset: 	1		;offset pointer by this value
min_rx_pwr: 	1
VGA_gain_set:	1
Tx_power_level:	1
RREQ_Tx_pwr:	1		;to store the power that we transmitted/forwarded the RREQ at so we can cache it on the way back
PARO_rt_id_d:	1
PARO_rt_id_s:	1
PARO_mod_loc_h:	1
PARO_mod_loc_l:	1
MOD_next_hop:	1
MOD_pwr:		1
RMOD_id_d:		1		;registers used to shuffle route ID's for memory cacheing when routes
RMOD_id_s:		1		;are modified
;***DSR AND PARO BUFFERS***
;radioin:		32		;radio input buffer - In data block for the meantime
;radioout:		32		;radio output buffer
;Used to Build Packets
dest_addr: 		1		;byte for the next address to hop to
source_addr:	1		;byte to store sender info
pkt_id: 		1		;byte to store the packet id
tx_pwr:			1
route_id_d: 	1		;reg to store the ID of current ROUTE - Destination
route_id_s:		1		;as above but for the source
hop_count:		1		;buffer to store the hop count for a RREQ packet
v_count_val:	1
v_count_diff:	1
;***Packet Identifiers***
RREQ:			1		;Code for Route Request
RREP:			1		;Route Reply
RUPD:			1		;Route Update - Maintenance
ACK:			1		;Acknowledge packet, for data transactions
DATA_PKT:		1		;data packet ID
RMOD: 			1		;route modify - from PARO
RMOD_ACK:		1		;also from PARO - yep change accepted TONTO
;***Physical Layer Registers***
coded_bits: 	1		;reserve space for the sampled input waveform
new_byte: 		1		;Reserve space to place all bits decoded from manchester into
temp_reg:		1		;temporary register used throughout for compare op's
current_bit: 	1		;bit to keep track of current symbol bit - a 1 in the current intersymbol bit location
bit_count:		1		;keep track of the number of bits decoded in byte
start_stop_bit: 1		;record of whether we are in the start/stop bit. A register so can be more that 1 period to give pause
symbol: 		1		;count of the symbols encoded (2, 1 or 0)
eor_bit: 		1		;bit used to manipulate the output
bit_tracker: 	1
send_byte: 		1		;PLACE BYTE TO TX NEXT IN HERE
receive_byte:	20		;buffer to store sample bytes in
sampled_bit:	1
wait_time:		1
rxbyte_offset:	1
fresh_byte:		1
current_sample:	1
temp_control:	1		;register to hold the layer control status so we can re-instate it once the Rx is through
timeout_counter:1
backup_len:		1
MAC_Stash_offset: 	1	;register to store to offset value that we have to load into from the start of radioin
WREG_Temp:		1
;****************************
;CRC Generation and Checking Registers
newData: 		1
crcLow:			1
crcHigh:		1
crcBytes:		1
Rx_Bytes:		1
Tx_Bytes:		1
receiveCRCLow:	1
receiveCRCHigh:	1
;****************************
;SPI Routine Registers
TXDATA:			1
RXDATA:			1
;****************************
;USART Registers
Tx_data_len:	1
Std_value:		1
ASCII_value:	1
USART_Tx_byte:	1		;byte to send over the UART
Low_String:		1
High_String:	1
;****************************
;***On-Board Route Storage***
current_on_board_h:		1
current_on_board_l:		1
max_location_h:			1
max_location_l:			1
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
